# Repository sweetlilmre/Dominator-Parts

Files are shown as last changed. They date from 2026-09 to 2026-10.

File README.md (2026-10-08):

# Kreepy Krauly Dominator replacement parts

This project gives 3D printed replacement parts for the Kreepy Krauly Dominator pool cleaner:

- **The cam assembly:** the cam, the gear and the washer. The cam controls the steering of the cleaner.
- **Gearbox parts:** the reduction gear, the two drive shafts and drive gears 1, 2 and 3.

The design is parametric OpenSCAD. All dimensions are in `scad/config.scad`. You can change them in the OpenSCAD Customizer.

Words in this README have the meanings in `CONTEXT.md`.

| Cam assembly | Cam | Gear |
|---|---|---|
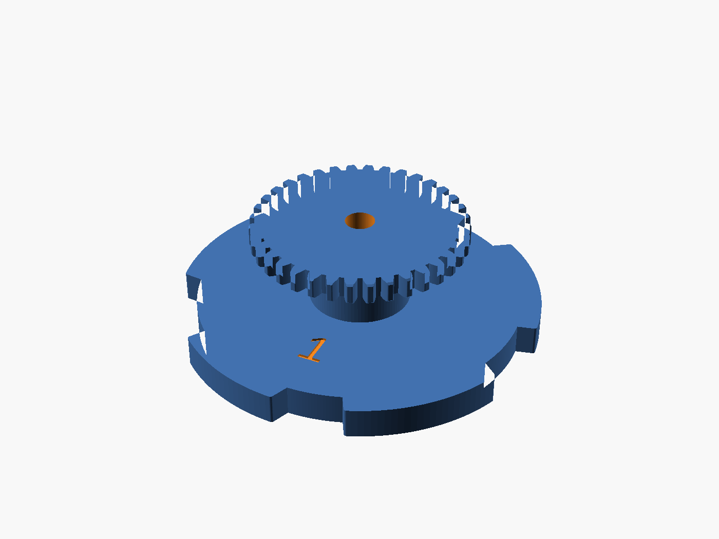
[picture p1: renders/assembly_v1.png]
Cam assembly
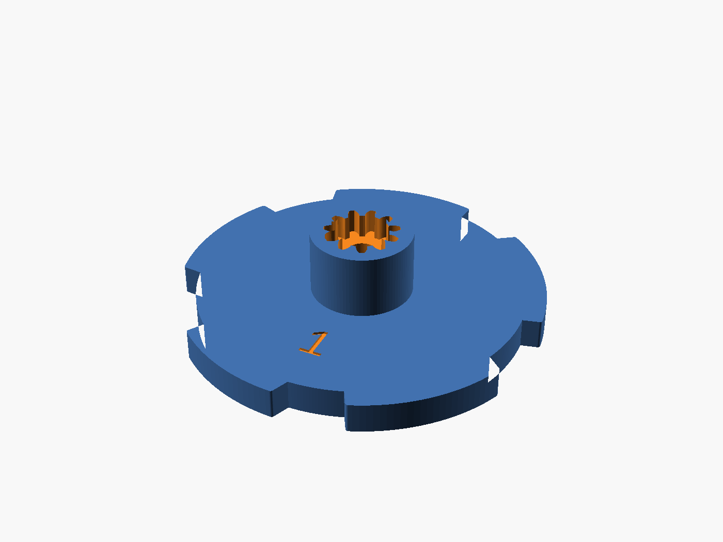
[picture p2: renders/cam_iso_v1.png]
Cam
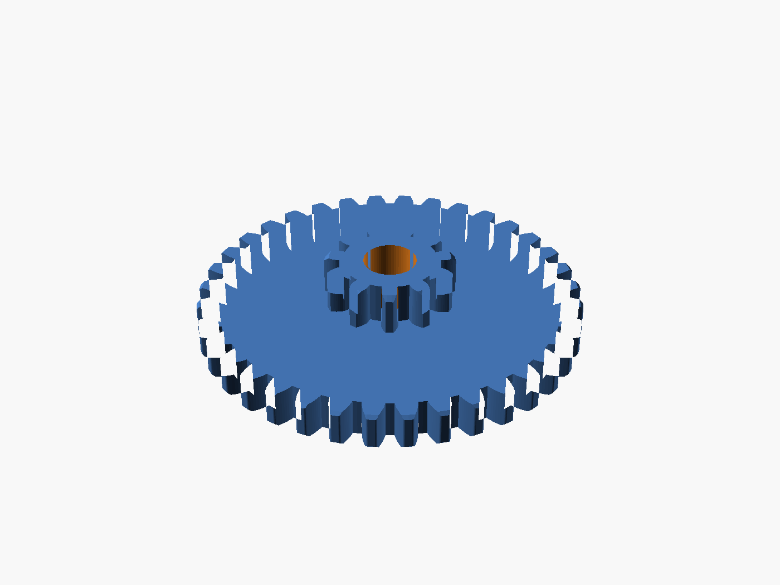
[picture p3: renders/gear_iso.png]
Gear
|  |  |  |

## Contents

1. [How the cam assembly works](#how-the-cam-assembly-works)
2. [The parts](#the-parts)
3. [Before you print: find the fit for your printer](#before-you-print-find-the-fit-for-your-printer)
4. [Modifiers: solid material where the parts wear](#modifiers-solid-material-where-the-parts-wear)
5. [Print the cam assembly](#print-the-cam-assembly)
6. [The two cam versions](#the-two-cam-versions)
7. [Gearbox parts](#gearbox-parts)
8. [Change the design](#change-the-design)
9. [Where the numbers come from](#where-the-numbers-come-from)
10. [Open items](#open-items)

## How the cam assembly works

The cam assembly turns on a steel pin in the gearbox. The gearbox drives the gear. The gear turns the cam.

The cam has five lobes on the rim of its plate. A follower in the gearbox rides on the rim. When a lobe comes to the follower, the follower goes up the ramp face and onto the crest. At the end of the lobe, the follower falls off the drop face into the next trough. Each lift of the follower changes the direction of the cleaner.

The cam and the gear are two separate printed parts:

- The **plug** on the hub side of the gear has spline teeth.
- The **socket** in the top of the hub has the same spline teeth.
- You push the plug into the socket. The gear then seats on the **shoulder** of the hub.
- The spline teeth transmit the torque. The shoulder holds the gear at the correct height.

Because the gear is a separate part, you can print a new gear without a new cam. You can also print it in a different material.

The **washer** goes on the pin between the gearbox wall and the cam side of the plate. It sets the position of the cam on the pin.

## The parts

| Part | What it does | STL file |
|---|---|---|
| Cam | The plate with the lobes, the hub and the socket. The follower runs on it. | `stl/dominator_cam_v1.stl` or `stl/dominator_cam_v2.stl` |
| Gear | The 36 tooth gear with the plug. It drives the cam. | `stl/dominator_gear.stl` |
| Washer | Sets the position of the cam on the pin. | `stl/dominator_washer.stl` |
| Fit test | A test part to find the spline fit for your printer. | `stl/dominator_fit_test.stl` |

Each part also has one or more modifier files. The section [Modifiers](#modifiers-solid-material-where-the-parts-wear) tells you which modifier goes with which part.

## Before you print: find the fit for your printer

The plug must be tight in the socket. If it is loose, the joint has play and the teeth wear. If it is too tight, the hub can split. Each printer makes holes and teeth a little differently, so the correct fit is different on each printer.

One value controls the fit: `spline_clearance` in `scad/config.scad`. It is the gap between the plug and the socket, in mm, on all sides of each tooth.

**Only the socket changes with `spline_clearance`.** The plug is always the nominal spline size. Thus you print the gear one time, and then you use it to test sockets.

| Printer | Material | Best `spline_clearance` |
|---|---|---|
| Owner's Prusa MK4 | PETG | 0.05 (the default) |
| A contributor's printer | not recorded | 0.15 |

These results show that the value is different on different printers. Do the test on your printer before you print a cam.

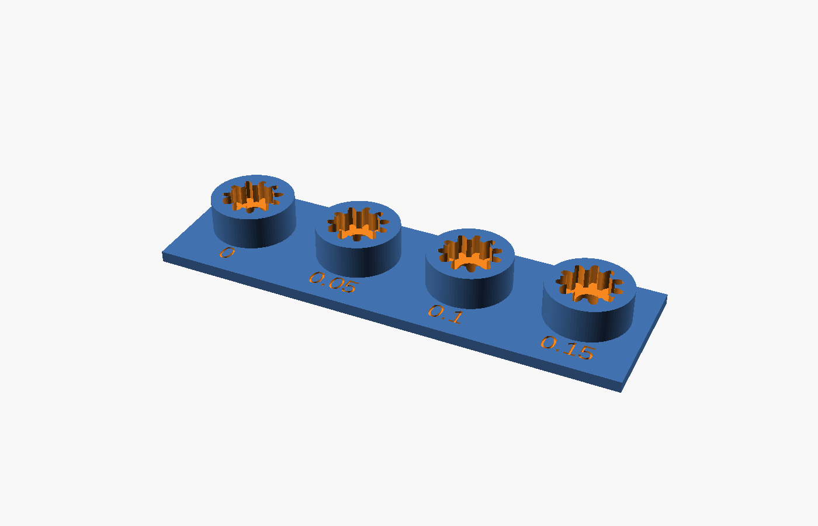
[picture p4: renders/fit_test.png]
Fit test


### Procedure

1. Print the gear (`stl/dominator_gear.stl`). Use its modifiers and the settings that you will use for the final parts.
2. Print the fit test (`stl/dominator_fit_test.stl`). Use the same material and settings. The fit test has four sockets, at clearances of 0, 0.05, 0.10 and 0.15. The clearance of each socket is engraved next to it.
3. Push the plug of the gear into each socket, one at a time.
4. Find the socket that holds the plug tightly without play. The socket must not crack.
5. Write the clearance of that socket in `spline_clearance` in `scad/config.scad`.
6. Export the cam again (see [Change the design](#change-the-design)).
7. Record the result in `PRINT_LOG.md`.

If no socket gives a good fit, change the list `ft_clearances` in `scad/fit_test.scad`. Then print the fit test again.

### Why the test uses a real gear

The fit test cuts its sockets with the same OpenSCAD module as the cam. The sockets are in the same orientation as the socket in the cam. Thus a socket in the fit test is equal to the socket in the cam.

The gear gives you a real plug. It has the print errors of the real part. A test plug with a different shape or orientation would have different errors.

### The clearance is on the cam

The cam has its `spline_clearance` engraved on both faces of the plate, opposite the version number. You can read the value in the slicer before you print. You can also read it on the printed part. This prevents a print from an old STL file.

## Modifiers: solid material where the parts wear

### Why the parts need modifiers

Some surfaces of the cam assembly rub against other parts:

- On the **cam**, the follower rubs on the crests, ramp faces, drop faces and troughs. The plug pushes against the walls of the socket.
- On the **gear**, the teeth mesh with the gearbox. The plug transmits the torque into the socket.

A normal print has a thin skin of perimeters on sparse infill. At a surface that rubs, the skin wears through quickly. A fully solid part does not have this problem, but it uses much time and material.

A modifier is a second mesh that you load onto a part in the slicer. The slicer applies the settings of the modifier only inside the modifier mesh. Each modifier in this project covers one area that rubs. Inside the modifier, the infill is 100 percent. The rest of the part uses your normal infill.

### Which modifier goes with which part

| Part | Modifier file | Area it makes solid |
|---|---|---|
| Cam | `stl/dominator_cam_rim_modifier.stl` | The outer band of the plate: from 4 mm inside the trough circle to outside the crests. This includes all the lobes and troughs. |
| Cam | `stl/dominator_cam_socket_modifier.stl` | The full width of the hub, from 1.5 mm below the floor of the socket to the shoulder. This includes the walls and floor of the socket. |
| Gear | `stl/dominator_gear_tooth_modifier.stl` | The teeth, and 4 mm inside the root circle. |
| Gear | `stl/dominator_gear_core_modifier.stl` | The plug, and the gear body directly below it. |
| Reduction gear | `stl/dominator_gear_tooth_modifier.stl` | The teeth of the ring, and 4 mm inside the root circle. |
| Reduction gear | `stl/dominator_gear_core_modifier.stl` | The pinion, the plate, and the ring directly below them. |

Both cam modifiers fit v1 and v2. The rim modifier has the size of the taller v2 lobes. On the v1 cam it goes past the crests, which has no effect.

Do not put a gear modifier on the cam. The plug on the gear and the socket on the cam are at different heights. Thus a gear modifier does not cover the socket.

### Put each setting in the correct place

- Set **Fill density = 100 percent on the modifier**. Do not add other settings to the modifier.
- Set **Perimeters on the part**, not on the modifier.

If you set perimeters on a modifier, the slicer makes perimeters around all edges of the modifier. This includes the inner edge of the ring in the middle of the plate. These perimeters have no function. When the modifier changes only the infill, the slicer does not make these perimeters.

### Procedure in PrusaSlicer

1. Import the STL of the part.
2. Right-click the part in the object list. Select Add settings, Layers and perimeters. Set Perimeters.
3. Right-click the part. Select Add modifier, Load. Select the modifier STL. The modifier has the same origin as the part, so it goes into the correct position. Do not move or scale it.
4. Right-click the modifier. Select Add settings, Infill. Set Fill density to 100 percent.
5. Do steps 3 and 4 again for the second modifier of the part.
6. Slice the part. In the preview, make sure that the areas in the table above show solid infill. Make sure that there is no ring of perimeters at the inner edge of a modifier.

`SLICING.md` gives more information about these settings.

## Print the cam assembly

Find the fit for your printer first. See [Before you print](#before-you-print-find-the-fit-for-your-printer).

| Part | Orientation | Perimeters | Modifiers | Supports |
|---|---|---|---|---|
| Cam | Cam side on the bed, hub up | 3 | rim and socket | none |
| Gear | Flat side on the bed, plug up | 3 | tooth and core | none |
| Reduction gear | Ring on the bed, pinion up | 3 | tooth and core | none |
| Washer | Flat | 3 | none, use 100 percent infill | none |

All STL files are in the correct orientation for printing. Do not turn them.

Settings for all parts:

- Layer height: 0.12 to 0.2 mm. Thinner layers give smoother tooth flanks.
- Nozzle: 0.4 mm.
- Material: PETG, ASA or nylon. Do not use PLA. PLA becomes soft in a hot pool.
- Speed: use a low speed for the external perimeters of the cam. The lobe faces are the surfaces that the follower runs on.

### Assemble

1. Push the plug of the gear into the socket of the cam. Push until the gear seats on the shoulder.
2. Put the washer on the pin.
3. Put the cam assembly on the pin, cam side to the washer.

## The two cam versions

The OEM cam has a number on both faces. Two numbers are known, v1 and v2. The owner has one of each. The two versions are the same in all measured dimensions, but for these:

| | v1 | v2 |
|---|---|---|
| Lobe height | 4 mm | 5 mm |
| Span across the crests | 79 mm | 81 mm |
| Lobe widths, in sequence | 49.9, 41.1, 46.0, 49.9, 49.5 deg | 50, 43, 41, 49.5, 49.5 deg |
| Largest trough | 32.5 deg | 35.5 deg |

Find the number on your old cam. Print the cam with the same number.

- In the Customizer, set `cam_version`.
- With `render.ps1`, use `-CamVersion v1` or `-CamVersion v2`.

The printed cam has its version number engraved on both faces, as the OEM cam does. Only the cam changes with the version. All other parts and all modifiers fit both versions.

| v1 | v2 |
|---|---|
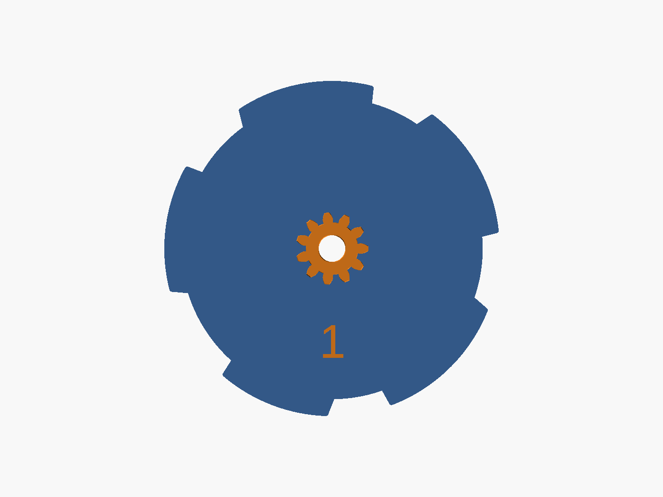
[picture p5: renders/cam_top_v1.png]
Cam v1
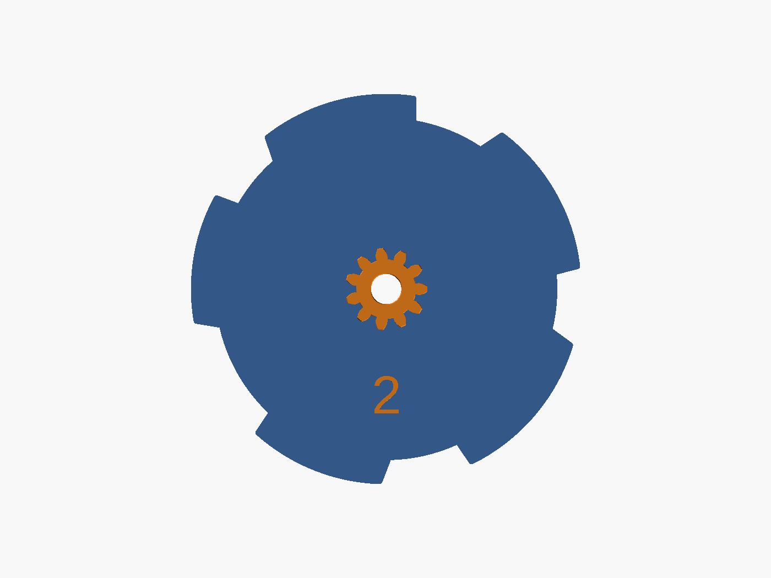
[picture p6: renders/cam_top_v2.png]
Cam v2
|  |  |

## Gearbox parts

These parts are not part of the cam assembly. They replace other worn parts in the gearbox. Use the same material as for the cam assembly.

### Reduction gear

`stl/dominator_reduction_gear.stl` is one of the gears between the turbine and the cam. It has a 36 tooth ring and an 11 tooth pinion on top. The pinion drives the gear of the cam assembly. Its dimensions are in the `[Reduction gear]` section of the config. They do not change when you change the gear of the cam assembly.

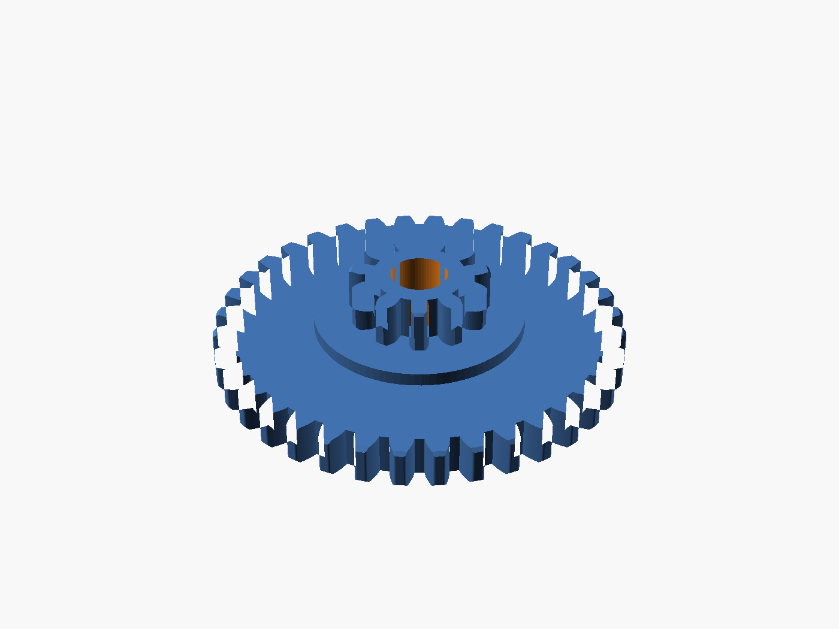
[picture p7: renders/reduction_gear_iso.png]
Reduction gear


### Drive shafts

`stl/dominator_shaft_long.stl` and `stl/dominator_shaft_short.stl` are the two drive shafts. Each drive shaft is an 8 tooth pinion along its full length, with round body sections.

| | Long | Short |
|---|---|---|
| Length | 177 mm | 83 mm |
| Gear tip diameter | 12.45 mm | 12.45 mm |
| Gear lengths, A end / B end | 12 / 50 mm | 18 / 25 mm |
| Body diameter | 12.5 mm, 10 mm between the gear seats | 12.5 mm |

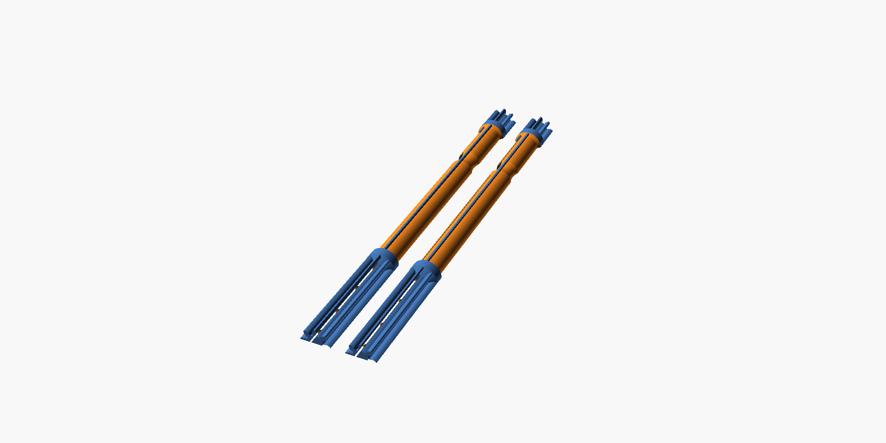
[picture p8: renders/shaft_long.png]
Long drive shaft


Each STL has two equal halves. The halves lie flat on the bed. You glue them together after printing.

- **Why halves:** A drive shaft printed vertically broke at the step between the gear and the body. The layer lines went across the drive shaft at that point. Flat halves put the layer lines along the drive shaft.
- **Split through the tooth centres:** Each half has whole teeth up. It has a half tooth flat on the bed at each side. Thus no tooth has an overhang.
- **Dowel holes:** A line of holes on the axis holds short pieces of 1.75 mm filament. The dowels align the two halves, also in the gear sections.
- **Root fillets:** A 2 mm cone at each body end goes into the tooth roots. This removes the sharp step where the vertical print broke.

To print and assemble a drive shaft:

1. Print the halves with 3 perimeters and 100 percent infill. The parts are small, so they do not need modifiers.
2. Put the dowels into the holes of one half.
3. Put the two halves together without glue. Make sure that they align.
4. Glue the halves. Clamp them along the full length. PVC pipe cement gave a strong joint (see `PRINT_LOG.md`).

All settings are in the `[Drive shafts]` section of the config.

### Drive gear 1

`stl/dominator_drive_gear_1.stl` is a compound gear from the gearbox. It has a
26 tooth gear with a 19 tooth gear on the same axis. It turns on the pin. The 19
tooth gear meshes with the pinion of a drive shaft.

| | 26 tooth gear | 19 tooth gear |
|---|---|---|
| Tip diameter | 35 mm | 26.25 mm |
| Face width | 10 mm | 11 mm |
| Module | 1.25 | 1.25 |

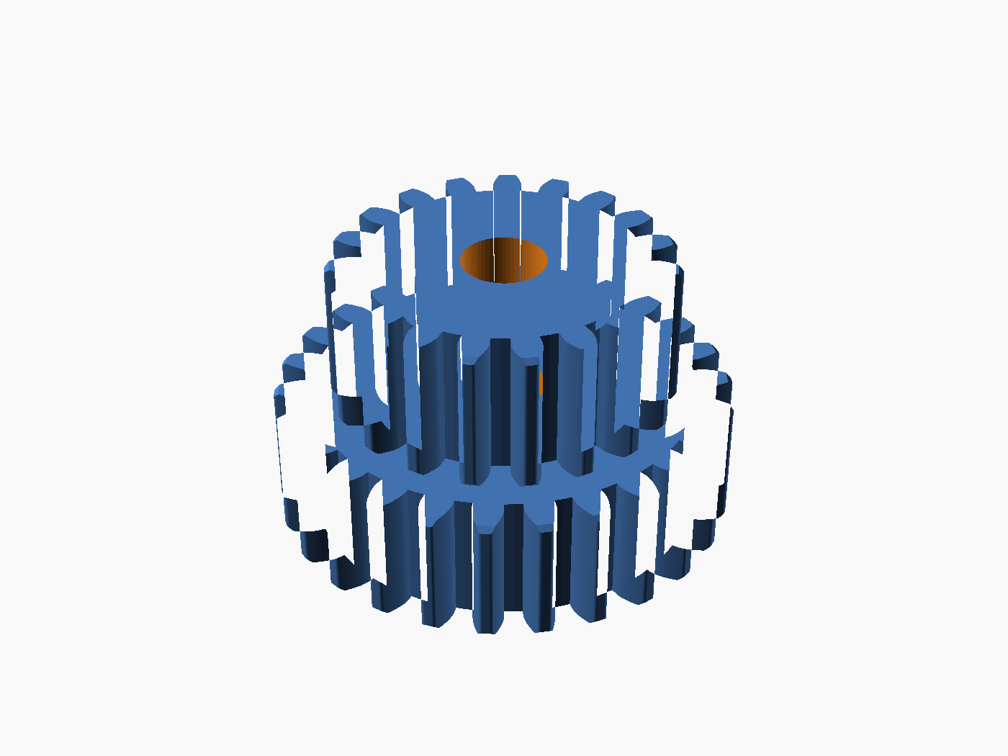
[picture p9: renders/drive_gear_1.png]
Drive gear 1


Both gears use one module. The module comes from the 26 tooth gear, because 26
is an even number: a caliper touches two opposite tooth tips, so the reading is
correct. 19 is an odd number, so a caliper cannot touch two opposite tips and
the reading is too small. The owner read 25 to 26 mm for a true 26.25 mm. The
model therefore calculates the 19 tooth diameter from the module. If you get a
better measurement, put the value in `dg1_inner_od`.

The teeth are a standard depth. They are not short like the teeth of the gear of
the cam assembly. The drive shaft pinion that this gear meshes with also uses
the standard depth.

The OEM part has slots in one face to save material. The printed part is solid.
The slots save moulding material and prevent shrinkage. A printed part does not
need this, and a solid part is stronger.

To print drive gear 1: put the 26 tooth gear on the bed. You do not need
supports. The bore goes through both gears.

All settings are in the `[Drive gear 1]` section of the config.

### Drive gear 2

`stl/dominator_drive_gear_2.stl` is a 23 tooth gear from the gearbox. It meshes
with the 19 tooth gear of drive gear 1. It has a spacer on each face. The
spacers hold the gear away from its neighbours on the pin, so they are a part of
the gear and not separate washers.

| Item | Value |
|---|---|
| Teeth | 23 |
| Tip diameter | 31.25 mm |
| Module | 1.25 |
| Gear body width | 15 mm |
| Spacer | 1.5 mm high, 14 mm diameter, one on each face |
| Total height | 18 mm |

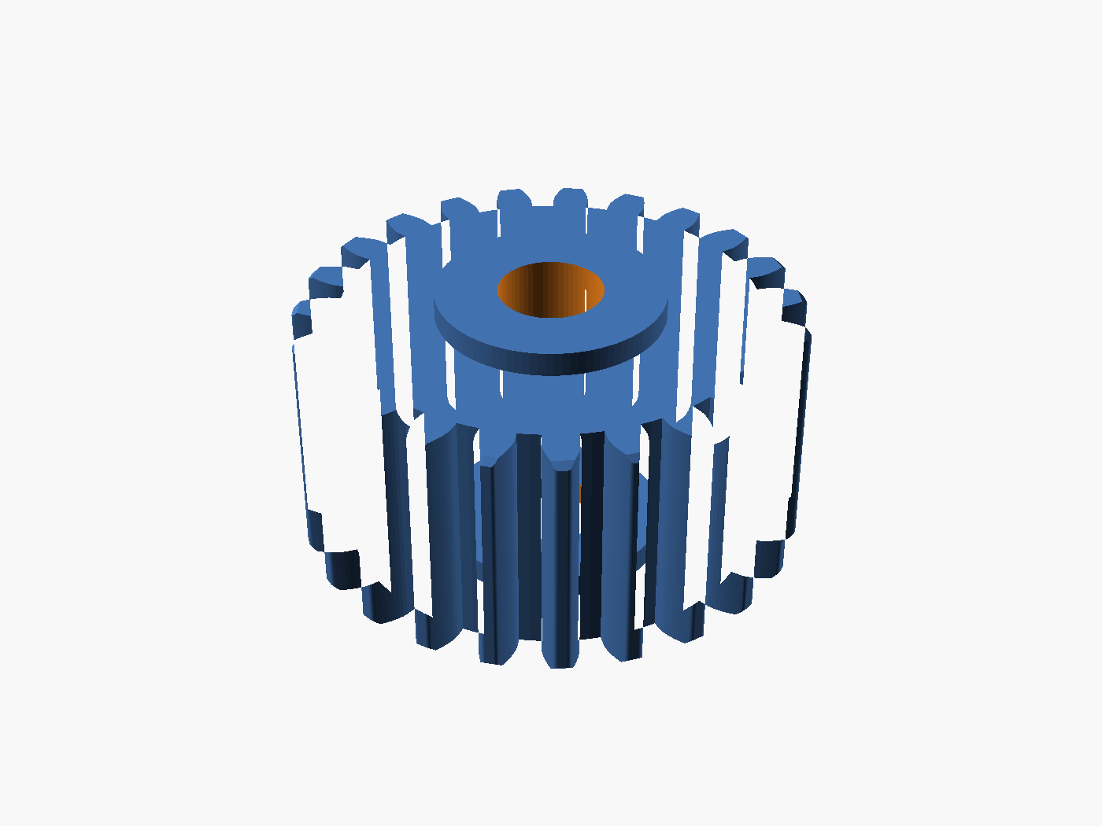
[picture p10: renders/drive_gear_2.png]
Drive gear 2


The module is not a value of its own. It comes from drive gear 1, because the
two gears mesh and meshing gears must have the same module.

The tip diameter is calculated from the module, not measured. 23 is an odd
number, so no tooth is opposite another tooth. A caliper cannot touch two
opposite tips, and the reading is too small: the owner read 30 mm for a true
31.25 mm.

The gear body is 15 mm. A trace of the side photograph gave 17 to 19 mm, but a
print showed that the caliper reading of 15 mm is correct (see `PRINT_LOG.md`).

To print drive gear 2: put one spacer on the bed. You do not need supports. The
spacer is small, so use a brim if the part comes loose.

All settings are in the `[Drive gear 2]` section of the config.

### Drive gear 3

`stl/dominator_drive_gear_3.stl` is a 26 tooth gear that connects the two drive shafts. Drive gear 2 turns it. It has a boss on each face. Each boss has an 8 lobe socket for a drive shaft:

- The long shaft goes into the long boss.
- The short shaft goes into the short boss.

The gear does not turn on the pin. It has no bore. A solid wall separates the two sockets.

| Item | Value |
|---|---|
| Teeth | 26 |
| Tip diameter | 35 mm |
| Module | 1.25 |
| Gear face width | 11 mm |
| Boss diameter | 18 mm |
| Short boss / long boss | 5 mm / 14 mm |
| Total height | 30 mm |
| Short socket / long socket depth | 17 mm / 12 mm |
| Wall | 1 mm, at the face of the gear on the long boss side |

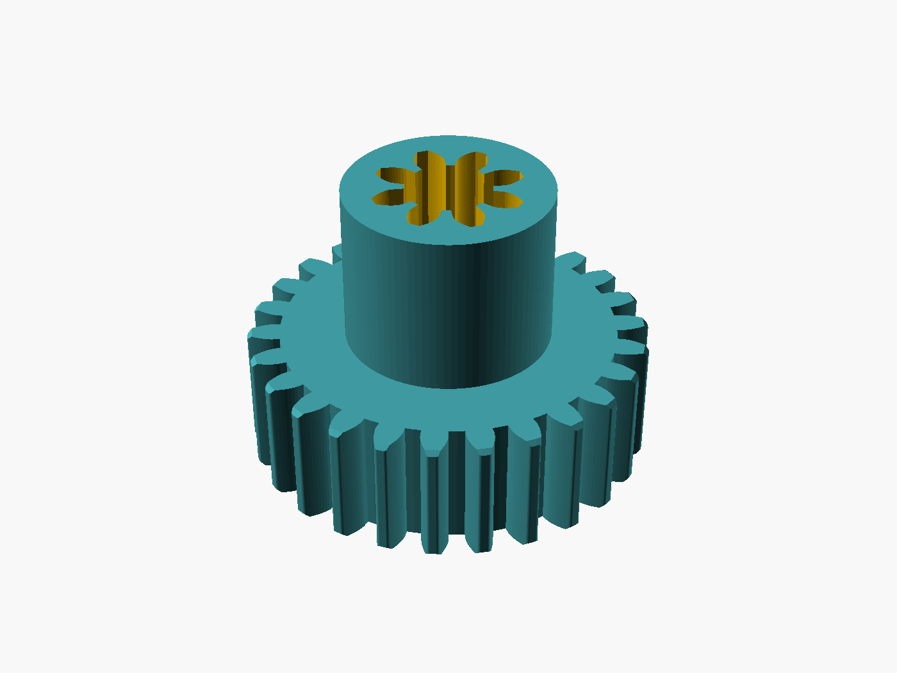
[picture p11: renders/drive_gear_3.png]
Drive gear 3


The module comes from drive gear 1, because drive gear 3 meshes with drive gear 2. The 35 mm tip diameter agrees: 26 is an even number, so the caliper reading is correct.

The sockets have the tooth profile of the drive shaft pinion. `dg3_socket_clearance` adds a gap of 0.3 mm on all sides. This gives a slide fit, because the shafts are loose in the OEM part. If a shaft is too tight or too loose, change the value and print the gear again.

To print drive gear 3:

1. Print it in one piece, as exported, with the short boss on the bed. You must use supports under the gear, because the gear is wider than the boss below it. Put supports only there: use paint-on supports or "Support on build plate only". Make sure that no supports go into the short socket, and tick "Don't support bridges". The wall between the sockets prints as a 13 mm bridge over the short socket.
2. If the part is not stable on the bed, use a brim.
3. Push each drive shaft into its socket. Make sure that it slides in and turns the gear without play.

All settings are in the `[Drive gear 3]` section of the config. Set `dg3_split = true` to print the gear in two halves instead. The halves are cut across the axis at the middle of the gear. They print on their cut faces, and you glue them together with four 1.75 mm filament dowels.

## Change the design

### Files

| Path | Contents |
|---|---|
| `scad/assembly.scad` | Open this file in OpenSCAD. Select `part` in the Customizer. |
| `scad/config.scad` | All parameters. Each value shows where it comes from. |
| `scad/cam.scad` | The cam, the washer and the cam modifiers. |
| `scad/cam_gear.scad` | The gear and the gear modifiers. |
| `scad/fit_test.scad` | The fit test. |
| `scad/reduction_gear.scad` | The reduction gear. |
| `scad/drive_shaft.scad` | The two drive shafts. |
| `scad/drive_gear.scad` | The drive gears. |
| `scad/lib/involute_gear.scad` | An involute spur gear library. It has no external dependencies. |
| `render.ps1` | Exports the parts to `stl/`. |
| `render_previews.ps1` | Makes the PNG images in `renders/`. |
| `PRINT_LOG.md` | One entry for each print: the config, the result, and the changes. |
| `SLICING.md` | More information about the slicer settings. |
| `CONTEXT.md` | The words for the parts and their features. |
| `measure/` | Photos with labels, and tables of the measurements to take, for each cam version. |
| `reference/` | The owner's photos of each cam version. |

### Export the STL files

You need the OpenSCAD command line. Install OpenSCAD from the official OpenSCAD website.

```powershell
.\render.ps1                          # all parts, cam version v1
.\render.ps1 cam gear                 # only the parts that you name
.\render.ps1 -CamVersion v2           # all parts, cam version v2
.\render_previews.ps1                 # the PNG images in renders\
```

The script works in Windows PowerShell 5.1 and in PowerShell 7. It uses `openscad.com`, the console version of OpenSCAD. Do not use `openscad.exe` for scripts: it is the GUI version, and it does not write files from the command line.

### Parameters that you can change

| Parameter | Default | What it does |
|---|---|---|
| `spline_clearance` | 0.05 | The gap between the plug and the socket. Find it with the fit test. |
| `bore_clearance` | 0.4 | The added diameter of the bore, so the cam turns freely on the pin. Use 0.3 to 0.5. |
| `gear_backlash` | -0.2 | A negative value makes the gear teeth thicker. The OEM teeth are thicker than a standard involute. If the gears bind, increase the value toward 0. |
| `plug_h` | 5 | How far the plug goes into the socket. The socket is `socket_extra` deeper, so the gear seats on the shoulder. |
| `ramp_lean`, `drop_lean` | 21, 9 | The lean of the ramp face and the drop face. 0 gives radial faces. |
| `cam_clearance_mark_size` | 5 | The text size of the engraved clearance. 0 removes it. |
| `socket_band` | 1.5 | How far the socket modifier goes below the floor of the socket. |

## Where the numbers come from

| Item | Value | Source |
|---|---|---|
| Trough circle | 71 mm | owner's calipers |
| Plate thickness | 6.6 mm | owner's calipers |
| Lobe height | v1 4 mm, v2 5 mm | owner's calipers; photo trace gives 4.15 and 4.5 |
| Lobe angles, v1 | 20.2-70.1, 90.4-131.5, 164-210, 235-284.9, 305.5-355 deg | traced from `reference/cam_v1/own_cam_top_v1.jpg` |
| Lobe angles, v2 | 15-65, 90-133, 168.5-209.5, 230-279.5, 305-354.5 deg | traced from `reference/cam_v2/own_cam_top_v2.jpg` |
| Lean | ramp face 21 deg, drop face 9 deg | line fit on each face in the same photo |
| Outline mirrored | `cam_mirror = true` | The trace photo shows the cam side. The gear side photo `reference/cam_v2/own_gear_side_v2.jpg` confirms the mirror. |
| Gear | 36 teeth, 47 mm tip diameter, 4.6 mm thick | owner's count and calipers |
| Gear tooth thickness | `gear_backlash = -0.2` | The OEM teeth are about 0.1 of the pitch thicker than a standard involute. Measured on `reference/cam_v2/own_gear_side_v2.jpg`. |
| Gear tooth depth | `gear_dedendum = 1.0` | The OEM teeth are about 2.4 mm deep, less than a standard tooth. Same photo. |
| Hub | 22 mm diameter, 14 mm from the plate to the shoulder | owner |
| Pin | 6.00 mm | owner. The worn OEM bore measured 6.3. |
| Washer | 2 mm | estimate |
| Reduction gear pinion | 11 teeth, 16 mm tip diameter | owner |

The outlines come from the owner's photos. The photos were taken straight down. They were scaled with the grid of the cutting mat and the trough circle measured on the ruler photos. The v1 method, applied to the v2 photo, gives the v2 lobe widths within 1.5 degrees. This is the accuracy of the lobe angles.

### The spline is not an OEM dimension

The plug, the socket and all `spline_*` parameters are a design of this project. They let you print the gear as a separate part. The photos do not show how the OEM parts join. Thus the division into a cam and a gear is a decision for printing. It is not a copy of the OEM part.

The spline has 11 teeth and a 16 mm tip diameter. This is the same size as the pinion of the reduction gear, so the project has one small tooth size. The spline and the pinion have separate parameters. The mesh with the gear controls the pinion. The hub wall and the fit control the spline. A change to one must not change the other.

The spline teeth are shorter than the pinion teeth (`spline_addendum` 0.9). This keeps more material around the bore.

## Open items

1. Measure `washer_t`: the distance from the gearbox wall to the cam side of the OEM plate.
2. Measure the stack height of the OEM cam assembly. Compare it with the stack height that OpenSCAD shows in the console.
3. Hold the printed cam with the gear side up and 0 degrees to your right. The ramp face of each lobe must be on the counter-clockwise side. If it is not, set `cam_mirror = false` and change the two lean values with each other.
4. Print the cam and the gear at `spline_clearance = 0.05`. The fit test found this value on the owner's printer, but the full parts are not yet printed at this value.

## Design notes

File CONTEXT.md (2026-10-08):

# Dominator Replacement Parts

Vocabulary for the 3D printed replacement parts of the Kreepy Krauly Dominator pool cleaner: the cam assembly and the gearbox parts. The cam turns in the gearbox and its lobes lift a follower that changes the cleaner's direction.

## Language

### Parts

**Cam assembly**:
The cam, gear and washer on the pin.
_Avoid_: cam kit, steering cam

**Cam**:
The flat lobed part that the follower runs on, with its hub. The part that wears.
_Avoid_: cam plate, cam disc, tray

**Cam version**:
Which moulding of the cam a part or measurement refers to, taken from the number stamped on both faces. v1 and v2 differ in the lobe pattern and the lobe height only. Selected by `cam_version`.
_Avoid_: revision, mark, type, generation

**Plate**:
The flat body of the cam from which the lobes and hub rise.
_Avoid_: floor, disc

**Hub**:
The upright cylinder on the cam that carries the gear and holds the socket.
_Avoid_: shaft, post, boss

**Gear**:
The 36 tooth spur gear that drives the cam, a separate part carrying the plug.
_Avoid_: ring gear, cam gear

**Washer**:
The flat ring on the pin between the gearbox wall and the cam.
_Avoid_: spacer, shim

**Pin**:
The steel rod through the gearbox on which the cam assembly turns.
_Avoid_: shaft, axle, spindle

**Follower**:
The part of the gearbox that rides on the cam's lobes and triggers the steering. Not part of the cam assembly.
_Avoid_: pawl, finger, follower gear

**Reduction gear**:
One of the gearbox gears between the turbine and the cam: a ring with a pinion on top. A gearbox part, not part of the cam assembly. Its ring reads the same as the gear today but is dimensioned separately.
_Avoid_: follower gear, compound gear, cam gear kit gear

**Gearbox parts**:
The printed replacements for gearbox parts outside the cam assembly: the reduction gear, the drive shafts and the drive gears.
_Avoid_: optional parts, extras

**Pinion**:
The small toothed wheel on top of a reduction gear that drives the next gear in the train.
_Avoid_: small gear, spur

**Drive shaft**:
One of the two long gearbox shafts, long and short, that carry an 8 tooth pinion profile along their length and transfer drive to the wheels. A gearbox part, not part of the cam assembly.
_Avoid_: axle

**Drive gear**:
One of the gears in the gearbox that drives the drive shafts. Numbered 1 to 3 after the owner's photographs. Drive gear 1 is a compound gear: a 26 tooth gear with a 19 tooth gear on the same axis. Drive gear 2 is a single 23 tooth gear and meshes with drive gear 1's 19 tooth gear. Drive gear 3 is a 26 tooth gear driven by drive gear 2; it does not turn on the pin but joins the long and short drive shafts, which fit into a socket in each of its two bosses. A gearbox part, not part of the cam assembly.
_Avoid_: drive shaft, idler, transfer gear

### Spline joint

**Spline**:
The involute tooth pattern shared by the plug and the socket, and by extension the joint they form. Carries torque from gear to cam.
_Avoid_: key, keyway

**Plug**:
The male toothed part on the underside of the gear.
_Avoid_: boss, post, spline post

**Socket**:
The female toothed hole in the top of the hub that receives the plug.
_Avoid_: pocket, bore

### Lobe geometry

**Lobe**:
One of the five protrusions on the rim of the plate that lifts the follower.
_Avoid_: ear, bump, tab, notch

**Trough**:
The stretch of rim between two lobes where the follower rests.
_Avoid_: gap, dwell, valley, notch

**Trough circle**:
The circle the rim follows in the troughs, from which the lobes rise. Its diameter is the rim diameter.
_Avoid_: base circle (reserved for gear geometry), root diameter

**Crest**:
The outer face of a lobe that the follower rides along while lifted.
_Avoid_: top, land, outer face

**Ramp face**:
The sloped side face of a lobe, about 21 degrees from radial, that the follower rides up onto the crest. It is on the counter-clockwise side of each lobe when viewed from the gear side, and is the first face to reach the follower.
_Avoid_: leading face, trailing face, steep face, start edge, end edge, sloped edge

**Drop face**:
The near-radial side face of a lobe, about 9 degrees from radial, that the follower falls off into the trough.
_Avoid_: leading face, trailing face, shallow face, straight edge

**Lobe height**:
How far the crest stands out beyond the trough circle.
_Avoid_: ear out, bump height, protrusion

**Lean**:
The angle between a ramp or drop face and the radial line through the face's mid-height point.
_Avoid_: rake, slope angle, draft

**Face position**:
The angle around the cam at which a face sits, always taken at mid-height of the face. Changing a lean pivots the face about this point.
_Avoid_: root angle, corner angle

**Rotation direction**:
Counter-clockwise when viewed from the gear side, observed in the gearbox, so each lobe presents its ramp face to the follower first.

### Orientation

**Gear side**:
The side of the cam assembly from which the gear is visible; the plate face the hub rises from.
_Avoid_: top, front

**Cam side**:
The opposite side, the flat face of the plate that sits against the washer and gearbox wall.
_Avoid_: bottom, back, wall side, underside

**Hub side**:
The face of the gear that carries the plug and seats on the shoulder.
_Avoid_: underside, back

**Flat side**:
The plain face of the gear, the one printed against the bed.
_Avoid_: top, outer face

**Shoulder**:
The flat top of the hub around the socket on which the gear's hub side seats.
_Avoid_: seat, land

**Stack height**:
The distance from the gearbox wall to the flat side of the gear: washer plus plate plus hub plus gear thickness.
_Avoid_: overall height, assembly height, stack

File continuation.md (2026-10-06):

# Continuation notes

State of the Dominator parts project as of 2026-09-22, written so a fresh session can resume with no other context. Read `CONTEXT.md` for vocabulary before touching anything; use its terms (lobe, trough, ramp face, drop face, hub, plug, socket, pin, follower, reduction gear, drive shaft, cam version).

## What this repo is

Parametric OpenSCAD replacements for wearing parts of a Kreepy Krauly Dominator pool cleaner gearbox. Owner: Peter. Remote: GitHub `sweetlilmre/Dominator-Parts`. Work is on branch `cam_alt_version`. Commit messages end with a `Co-authored-by` trailer.

Files: `scad/assembly.scad` is the entry point (Customizer `part` and `cam_version` selectors), `scad/config.scad` holds every parameter with a source tag, `scad/lib/involute_gear.scad` is a dependency-free involute gear library. `render.ps1` exports STLs, `render_previews.ps1` regenerates the PNGs in `renders/`. `PRINT_LOG.md` records each physical print. `SLICING.md` explains perimeters versus infill and the modifier meshes. `measure/cam_v1/` and `measure/cam_v2/` hold the annotated measurement sheets. `reference/cam_v1/` and `reference/cam_v2/` hold the owner's photographs, and are tracked.

OpenSCAD 2021.01 is at `C:\Program Files\OpenSCAD\openscad.com`. Use the `.com`, not the `.exe`: the `.exe` is the GUI build and detaches without rendering.

## The two cam versions

The cam is moulded with a number on both faces. The owner has one of each. They differ in exactly two parameters, both on the plate:

| | v1 | v2 |
|---|---|---|
| `lobe_height` | 4 | 5 |
| Lobe widths | 49.9, 41.1, 46.0, 49.9, 49.5 | 50, 43, 41, 49.5, 49.5 |
| Largest trough | 32.5 deg | 35.5 deg |
| Outer span | 79 mm | 81 mm |

Everything else reads the same: trough circle 71, plate 6.6, hub 22 x 14, gear 36 T at 47, bore for a 6.0 mm pin. Select with `cam_version`, or `-CamVersion` on the scripts. Only the cam STL carries a `_v1` / `_v2` suffix; the rim modifier is sized from the taller lobes so one file serves both.

The printed cam engraves its version digit 0.5 mm into both faces, as the OEM moulding carries it (`cam_version_number_*`), and the `spline_clearance` its socket was cut at on the opposite side (`cam_clearance_mark_size`).

## Current design state

- **Cam**: flat plate 6.6 thick, trough circle 71, five lobes at the traced angles above, ramp face lean 21, drop face lean 9, `cam_mirror = true`. Hub 22 dia, 14 high, with an 11 tooth socket 16 mm across.
- **Gear**: 36 teeth, 47 OD, 4.6 thick, backlash -0.2, dedendum 1.0, tip round 0.3, with a matching 11 T / 16 mm plug. Prints flat side down, plug up.
- **Spline joint**: 11 T, 16 mm tip to tip, `spline_clearance = 0.15`. Sized to match the reduction gear pinion so the project has one small tooth size, but kept as separate parameters so a change to one cannot silently alter the other.
- **Washer** 2 x 16. Pin 6.0, bore clearance 0.4, bore 6.4.
- **Reduction gear**: owns its ring dimensions (`rg_ring_*`, 36 T at 47, 4.6 thick) rather than borrowing the cam gear's. Pinion measured at 11 T / 16 mm.
- **Drive shafts**: unchanged since 2026-09-10.
- **Fit test coupon** (`part = "fit_test"`): a plate of sockets at several clearances, pressed onto a printed gear's plug to find the fit without reprinting the cam.

## Decisions worth not relitigating

- **The reduction gear ring is decoupled from the cam gear.** They are different parts. The earlier arrangement, where the ring read `gear_teeth` and `gear_thickness` directly, meant editing the cam gear reshaped the reduction gear silently.
- **The pinion module is checked, not shared.** The pinion must mesh with the cam gear, so `assembly.scad` echoes a warning if the two modules differ by more than 2 percent. The old 12 T / 14.4 mm estimate was 16.8 percent out and could never have meshed; that is what the check exists to catch.
- **The spline is not an OEM dimension.** Earlier revisions of the README claimed the printed pieces were joined the same way as the OEM kit. Nothing in the photographs supports that, and the mating faces are never visible in any of them. The plug, socket and every `spline_*` value are this project's own design. How the OEM assembly divides is unresolved.
- **Tolerance scheme.** `spline_clearance` is applied as `offset(delta = clearance)` on the socket profile, so it is the gap normal to every flank, root and tip, and it does not scale with tooth count or diameter. Changing the spline size does not require retuning the fit.

## Measurement method and its traps

Outlines are segmented from the owner's straight-down photographs, sampled as radius against angle about the centroid, and scaled by the cutting-mat grid anchored to the trough circle from the ruler photograph. Running the pipeline over the v2 photograph reproduces the v2 lobe widths already in the config to within 1.5 degrees, which is the accuracy to trust.

Two traps, both hit during this work:

- **Parallax.** A ruler resting on the part sits about 12 mm closer to the lens than the mat it lies on, magnifying it by roughly 4 percent at phone range. Scale from a feature in the same plane as the thing being measured.
- **EXIF rotation.** Some photographs carry an orientation flag; `reference/cam_v2/own_cam_top_v2.jpg` is flagged 180 degrees. Libraries that ignore it read the array unrotated, silently rotating every angle measured from it.

## Open questions

1. **`spline_clearance` disagreement.** The fit test coupon says 0.15 grips best. Print 1 used 0.15 at the older 12 T / 14 mm spline and reported play. The differences are the spline size, the slicer settings (print 1 was PETG, 0.2 mm, 2 perimeters, 15 percent infill; the coupon's are unrecorded) and the host geometry (a 47 mm gear and 71 mm cam then, small pucks now). Unresolved; check the real parts.
2. **`washer_t`** has never been measured on either version: gearbox wall to the underside of the cam.
3. **v1 is only partly measured.** `plate_t`, `hub_h`, `hub_d`, `gear_od`, `gear_thickness` and both edge leans are assumed the same as v2. The leans are the ones worth checking, since the lobe widths differ.
4. **Print 2 of the cam assembly** has still never been reported.

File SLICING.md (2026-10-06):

# Slicing the cam assembly in PrusaSlicer

How to slice the cam and gear so the surfaces that rub are solid, without paying for a solid part everywhere. Terms follow `CONTEXT.md`.

## What needs to be strong

- **Cam**: the lobes and troughs. The follower runs on the crests, ramp faces, drop faces and troughs, so the outer band of the plate takes all the wear. The middle of the plate and the hub carry little load.
- **Gear**: the teeth, and the plug. The teeth mesh with the drive; the plug carries the torque into the socket.

Print 1 used 2 perimeters and 15 percent grid infill. That leaves a 0.9 mm skin over sparse infill at every contact surface, which is why it will wear quickly.

## The two settings, and where to put them

**Fill density** does the structural job. At 100 percent the region is solid and there is no skin to wear through.

**Perimeters** is a refinement. Perimeter lines follow the outline, so the material directly behind a lobe face is continuous extrusion running along the face. Solid infill is laid in parallel lines at 45 degrees, so at the face it ends in short segments meeting the wall at an angle, and it can leave tiny voids in narrow corners. A few perimeters give a tougher, cleaner contact skin with no wall-to-infill seam, but once the infill is solid more than 3 or 4 adds little. On the gear more perimeters can be worse: the teeth are so narrow they become nothing but perimeter anyway.

Put them in different places:

- **Fill density = 100 percent on a modifier**, so only the contact band is solid. A modifier that changes only infill does not create extra perimeters, because regions with the same perimeter settings are merged when perimeters are generated.
- **Perimeters on the object**, not on a modifier. If the perimeter count is set on a modifier, the modifier becomes its own region and the slicer draws perimeters around its whole boundary, including the inner edge of the ring in the middle of the plate. On the object, the only boundaries are the real outline and the bore.

## Recommended settings

| Part | Object setting | Modifier | Modifier setting |
|---|---|---|---|
| cam | Perimeters 3 | `stl/dominator_cam_rim_modifier.stl` and `stl/dominator_cam_socket_modifier.stl` | Fill density 100 percent |
| gear | Perimeters 3 | `stl/dominator_gear_tooth_modifier.stl` and `stl/dominator_gear_core_modifier.stl` | Fill density 100 percent |
| reduction gear | Perimeters 3 | `stl/dominator_gear_tooth_modifier.stl` and `stl/dominator_gear_core_modifier.stl` | Fill density 100 percent |
| washer | Perimeters 3, 100 percent infill globally | none | |

If you prefer one number, leave both objects at 3 perimeters and let the modifiers do the work. Going to 6 perimeters on the cam is harmless but unnecessary once the rim band is solid.

Other settings worth using:

- Slow the external perimeter speed on the cam, since the lobe faces are the working surface.
- 0.12 to 0.2 mm layers, 0.4 mm nozzle. Finer layers give smoother tooth flanks.
- PETG, ASA or nylon. PLA goes soft in a hot pool box.
- No supports on any part in the exported orientations: cam plate down and hub up, gear flat side down and plug up.

## Steps in PrusaSlicer

1. Import the part STL.
2. Right click the part in the object list, Add settings, Layers and perimeters, set Perimeters.
3. Right click the part, Add modifier, Load, pick the modifier STL. It is exported on the same origin and in the same orientation as the part, so it lands in place. Do not move or scale it.
4. Right click the modifier, Add settings, Infill, set Fill density to 100 percent. Add nothing else to the modifier.
5. Repeat 3 and 4 for the second modifier on each part.
6. Slice and check the preview: the rim band, hub around the socket, teeth and plug should show solid infill, the rest of the plate your global infill, and there should be no ring of perimeters at the modifier's inner edge.

## What the modifiers cover

| Modifier | Covers | Config value |
|---|---|---|
| `dominator_cam_rim_modifier` | outer band of the plate from 4 mm inside the trough circle to beyond the crests, plus half a millimetre above and below the plate | `rim_band` |
| `dominator_cam_socket_modifier` | the whole hub width from 1.5 mm below the socket floor to above the hub top, so the socket walls and floor are solid; one file fits either version | `socket_band` |
| `dominator_gear_tooth_modifier` | the teeth and 4 mm inside the root circle, full ring thickness, on the gear and on the reduction gear. One file fits both | `gear_band` |
| `dominator_gear_core_modifier` | on the gear, the plug and the gear body directly under it; on the reduction gear, the pinion, the plate and the ring under them. One file fits both | |

They are OpenSCAD parts in `scad/assembly.scad`, regenerated by `render.ps1`, so they track any change to the geometry.

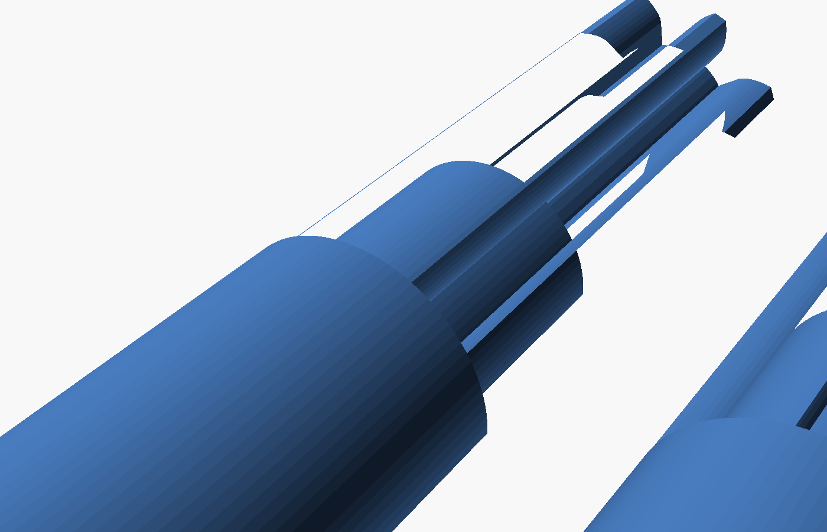
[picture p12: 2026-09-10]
renders/shaft_short_detail.png

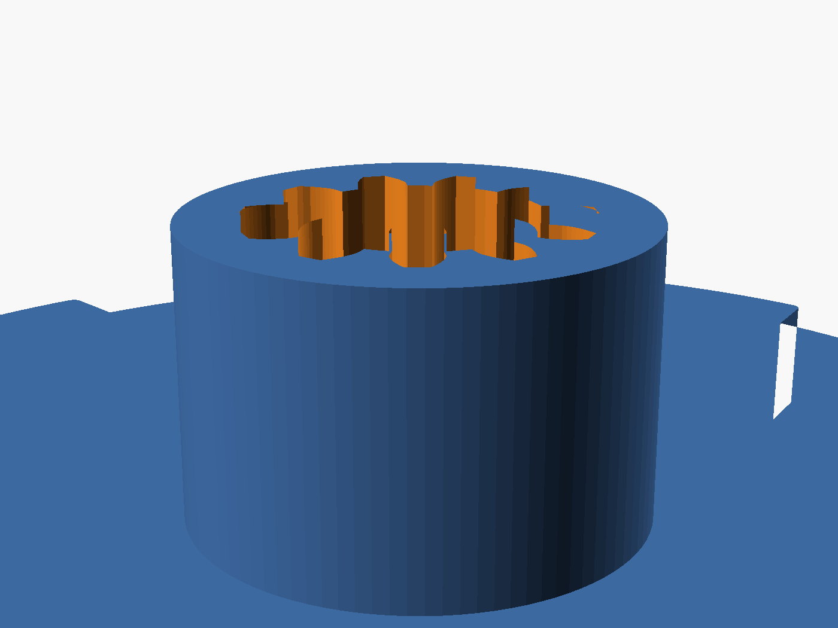
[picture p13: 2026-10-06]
renders/spline_closeup.png

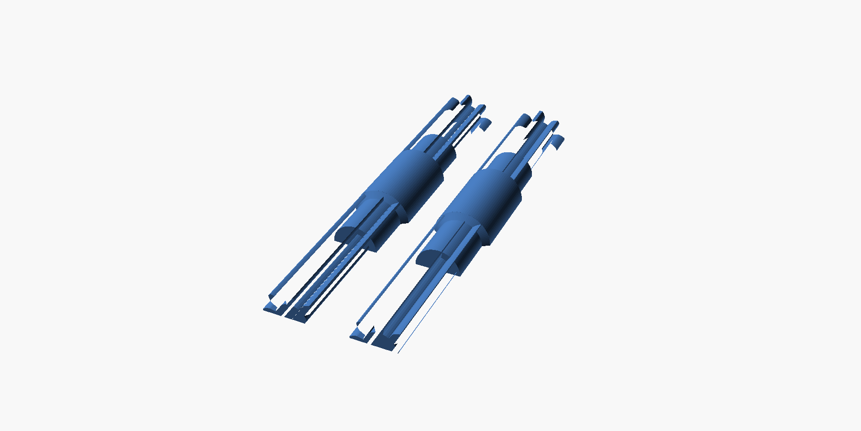
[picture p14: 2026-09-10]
renders/shaft_short.png

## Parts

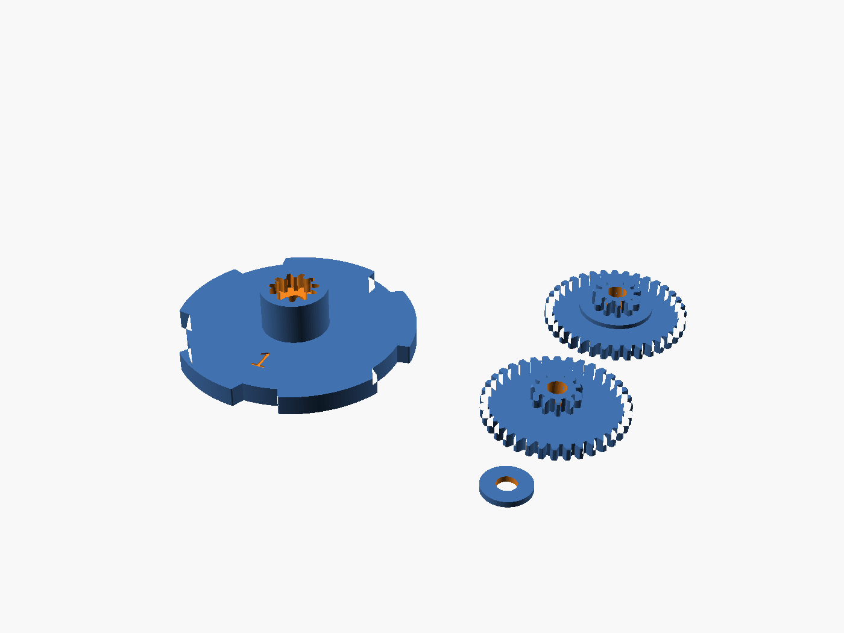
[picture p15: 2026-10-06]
renders/all_parts_v1.png

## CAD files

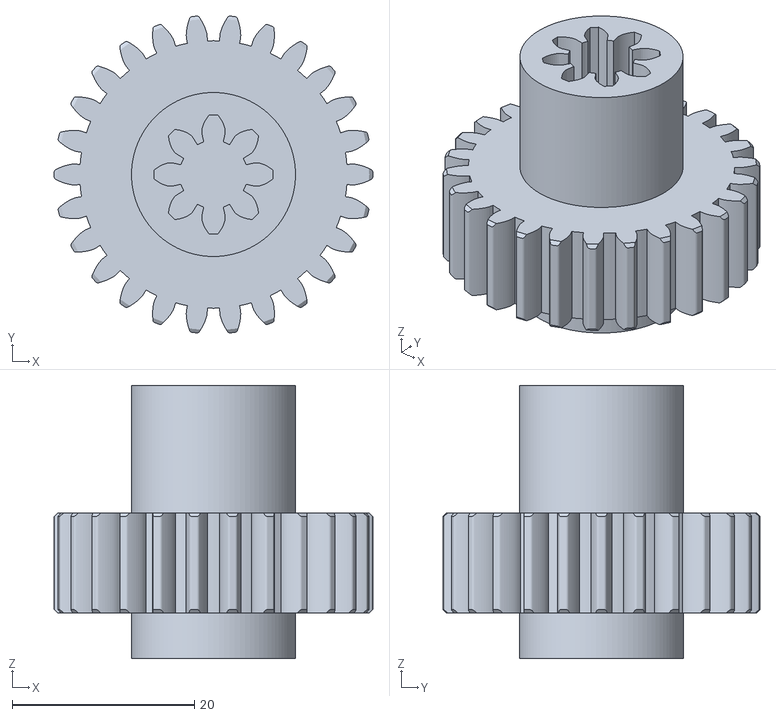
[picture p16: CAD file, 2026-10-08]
stl/dominator_drive_gear_3.stl
35.0 x 34.8 x 30.0

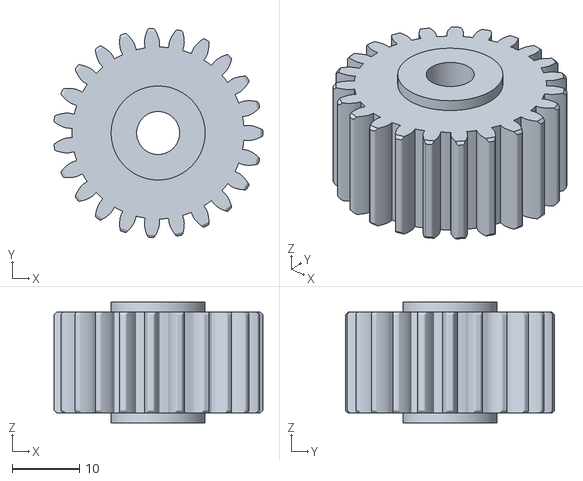
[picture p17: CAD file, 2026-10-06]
stl/dominator_drive_gear_2.stl
31.1 x 31.2 x 18.0

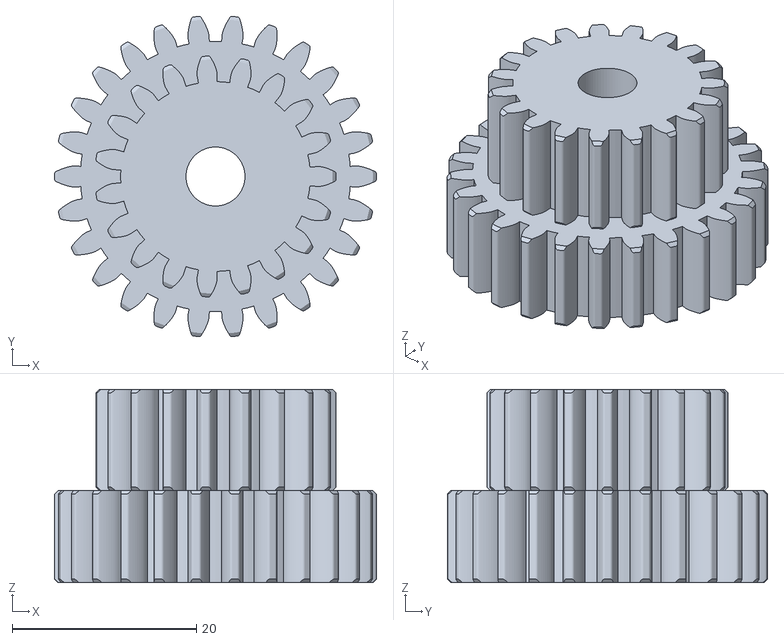
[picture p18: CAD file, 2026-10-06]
stl/dominator_drive_gear_1.stl
35.0 x 34.8 x 21.0

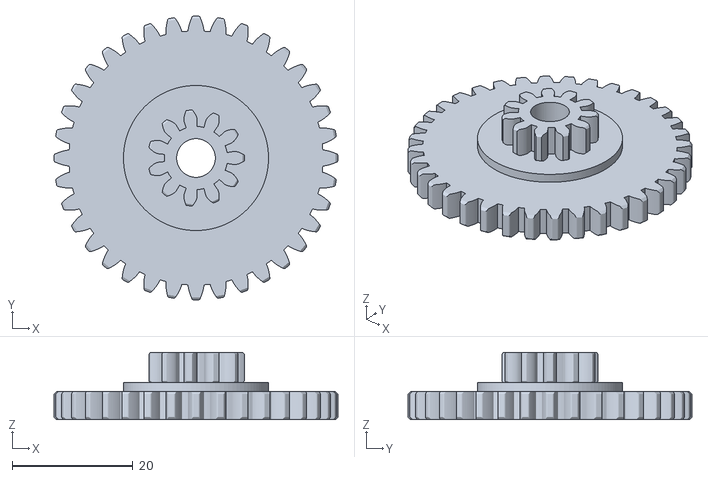
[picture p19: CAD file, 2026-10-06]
stl/dominator_reduction_gear.stl
47.0 x 47.0 x 11.1

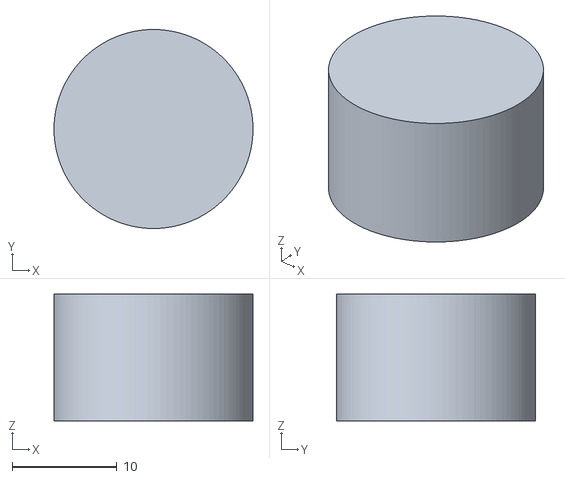
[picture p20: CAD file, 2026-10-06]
stl/dominator_gear_core_modifier.stl
19.0 x 19.0 x 12.1

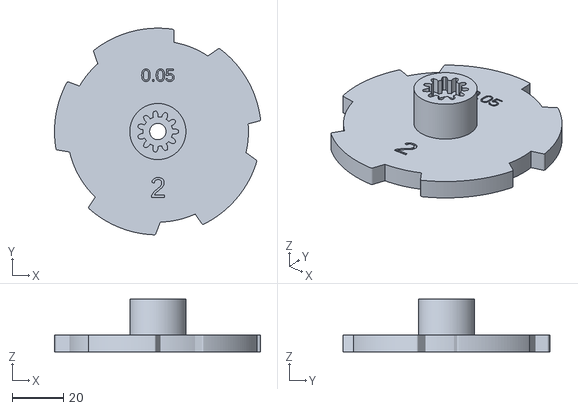
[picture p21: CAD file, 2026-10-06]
stl/dominator_cam_v2.stl
80.7 x 81.0 x 20.6

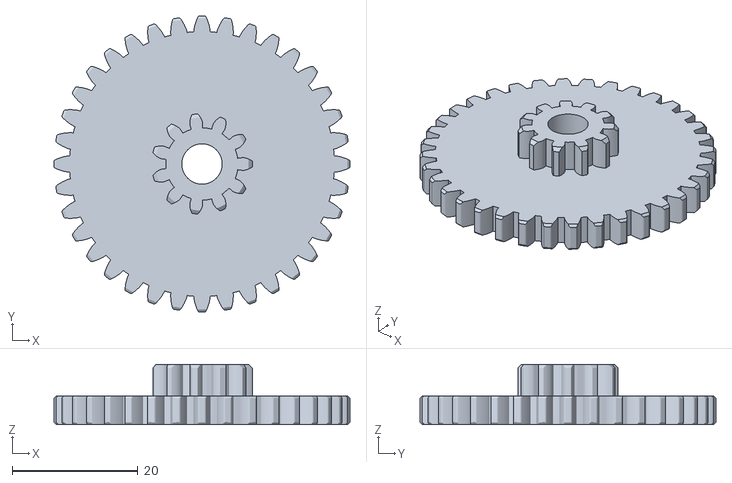
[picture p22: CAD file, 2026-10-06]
stl/dominator_gear.stl
47.0 x 47.0 x 9.60

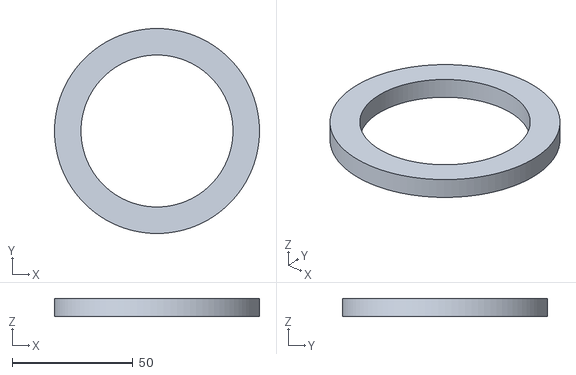
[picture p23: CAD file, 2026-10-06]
stl/dominator_cam_rim_modifier.stl
85.0 x 85.0 x 7.60

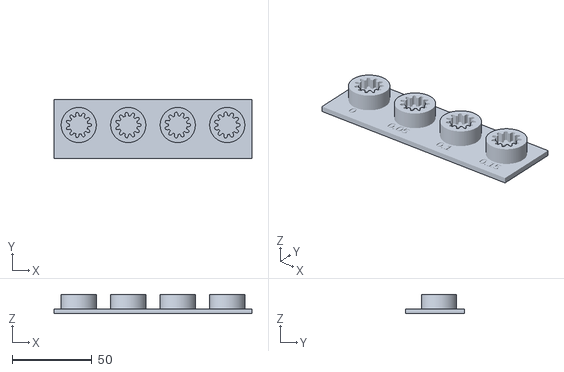
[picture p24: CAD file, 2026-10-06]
stl/dominator_fit_test.stl
124.0 x 37.2 x 12.0

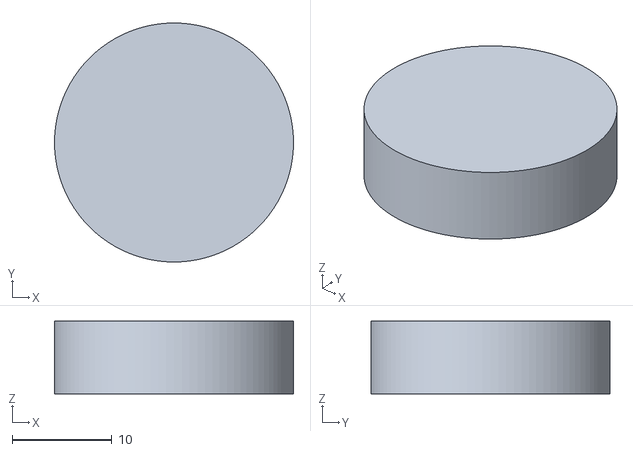
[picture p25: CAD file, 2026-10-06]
stl/dominator_cam_socket_modifier.stl
24.0 x 24.0 x 7.30

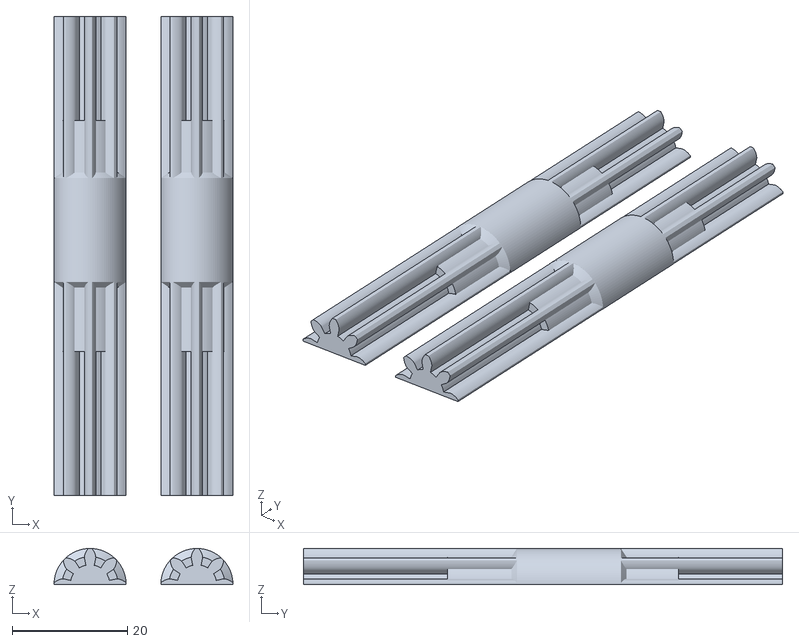
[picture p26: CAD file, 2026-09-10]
stl/dominator_shaft_short.stl
31.0 x 83.0 x 6.25

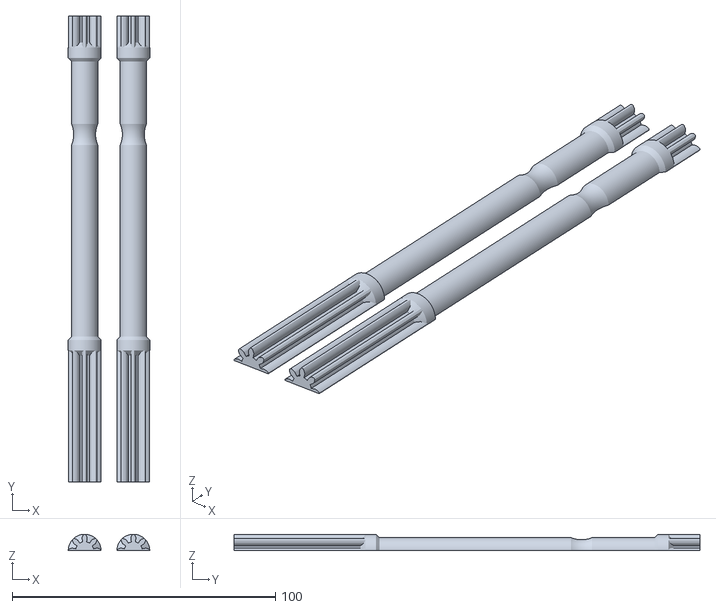
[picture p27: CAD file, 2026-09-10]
stl/dominator_shaft_long.stl
31.0 x 177.0 x 6.25

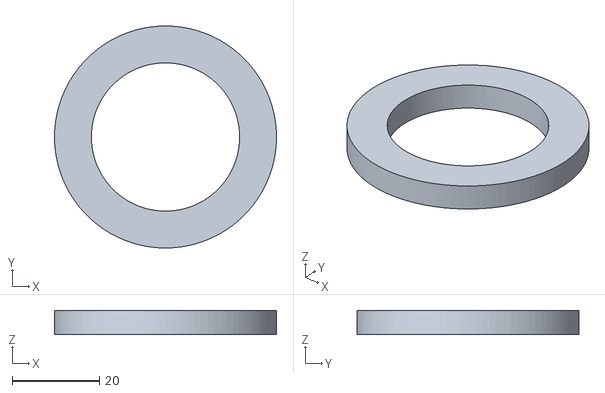
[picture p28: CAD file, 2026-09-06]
stl/dominator_gear_tooth_modifier.stl
51.0 x 51.0 x 5.60

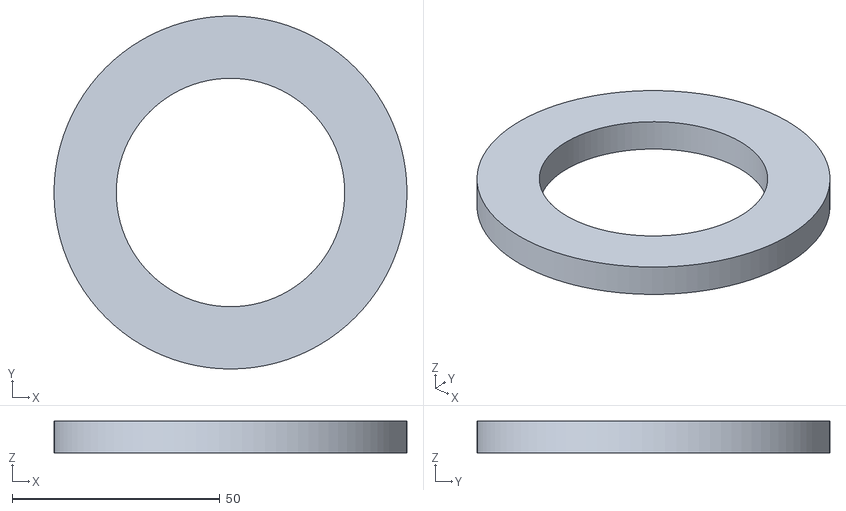
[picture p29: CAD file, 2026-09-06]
stl/dominator_rim_modifier.stl
85.0 x 85.0 x 7.60

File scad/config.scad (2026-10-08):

// config.scad - every tunable dimension for the Dominator cam + gear.
//
// Two printed pieces plus an optional washer:
//   cam   flat plate with the lobe outline, an integral hub rising
//         from it, and a socket in the top of the hub
//   gear  the 36 tooth ring gear with a matching plug underneath,
//         plugs into the socket and seats on the hub shoulder
// The steel pin runs through the bore of both.
//
// Sources: (owner) caliper readings on the worn part, (trace) measured from
// the owner's straight-down photo reference/cam_v2/own_cam_top_v2.jpg scaled to the
// 71 mm rim, (est) still an estimate.

include <lib/involute_gear.scad>

/* [Steel pin and bore] */
// Diameter of the steel pin the cam spins on. (owner) An earlier reading of
// the worn OEM bore gave 6.3; the v1 photo traces read it at 6.1 to 6.4. The
// pin itself is 6.00. The printed bore is pin + clearance.
pin_d = 6.00;
// Extra diameter so the cam spins freely on the pin. 0.3-0.4 typical for FDM.
bore_clearance = 0.4;
bore_d = pin_d + bore_clearance;

/* [Cam version] */
// The cam is moulded with a version number on both faces. The two versions
// share every dimension measured so far except the lobe pattern and the lobe
// height, so only those two are switched below. (owner)
cam_version = "v1"; // ["v1", "v2"]
// The OEM cam carries its number moulded into both faces. The printed cam
// engraves the same digit, taken from cam_version, so a printed part can be
// told apart from the other version once it is off the bed. 0 = no mark.
cam_version_number_size = 8;
// How deep the digit is cut into each face.
cam_version_number_depth = 0.5;
// Where the digit sits: radius from the centre, and angle around the plate.
// Must clear the hub and stay inside the trough circle.
cam_version_number_r = 22;
cam_version_number_angle = 270;
// The spline_clearance value (e.g. "0.05") is engraved the same way on the
// opposite side of the plate, so a cam sliced from a stale STL shows the
// clearance it was cut at. Same depth and radius as the digit. 0 = no mark.
cam_clearance_mark_size = 5;

/* [Cam plate] */
// Diameter of the trough circle of the rim, not across the lobes. (owner)
trough_d = 71;
// Plate thickness. This is the height of the lobe face the follower runs on. (owner)
plate_t = 6.6;
// How far each lobe protrudes beyond the trough circle, per version.
// (owner; v1 trace 4.15, v2 trace 4.5)
v1_lobe_height = 4;
v2_lobe_height = 5;
// Lobes as [start_deg, end_deg] at mid-height of the lobe, counter-clockwise
// seen from the gear side, 0 deg = +X. An optional third value overrides
// lobe_height for that lobe.
// v1 (trace) measured from reference/cam_v1/own_cam_top_v1.jpg, scaled by the
// cutting-mat grid and anchored to the 71.5 mm trough circle read off
// reference/cam_v1/own_cam_top_ruler_v1.jpg.
v1_lobes = [ [20.2, 70.1], [90.4, 131.5], [164, 210], [235, 284.9], [305.5, 355] ];
// v2 (trace) from reference/cam_v2/own_cam_top_v2.jpg. Re-measuring that photo
// with the v1 pipeline reproduces these widths to within 1.5 deg.
v2_lobes = [ [15, 65], [90, 133], [168.5, 209.5], [230, 279.5], [305, 354.5] ];
// The two differ in the narrow pair of lobes (v1 41.1 and 46.0 deg wide
// against v2 43 and 41) and in the largest trough (v1 32.5, v2 35.5 deg).
lobes       = cam_version == "v1" ? v1_lobes : v2_lobes;
lobe_height = cam_version == "v1" ? v1_lobe_height : v2_lobe_height;
// Rotate the whole lobe pattern (deg). Cosmetic, the gear is round.
lobe_rot = 0;
// Mirror the whole outline (lobe order and edge leans together). The photo
// used for the trace was taken looking at the non-gear side, and the owner
// confirmed the lean runs the other way when the part is held gear side up.
// Set false if a future trace is made from the gear side.
cam_mirror = true;
// Lean of the lobe edge faces from radial, deg. Positive = the face leans
// toward the middle of its lobe going outward. (trace) In the photo's view
// the clockwise edge leans 21 and the counter-clockwise edge 9; with
// cam_mirror = true the ramp face ends up on the counter-clockwise side
// when seen from the gear side. 0 = square radial steps.
ramp_lean = 21;
drop_lean = 9;
// Rounding of the outline corners (mm). 0 = sharp.
plate_corner_round = 0.6;

/* [Hub on the cam] */
// Hub outside diameter. The gear seats on the shoulder at its top. (est)
hub_d = 22;
// Hub height from the plate top to the gear underside. (owner)
hub_h = 14;

/* [Spline joint between hub and gear] */
// As in the OEM kit: the gear carries a plug on its underside, the top
// of the hub has a matching socket. The plug is an involute
// pinion profile. The gear seats on the flat shoulder of the hub around the
// socket, so the teeth only carry torque and do not locate the gear.
// Not an OEM dimension: the OEM gear and cam mate differently, so the spline
// is free design. (design) Sized to match the reduction gear pinion at
// 11 T / 16 mm so the project has one small tooth size rather than two nearly
// identical ones. Deliberately a SEPARATE parameter from rg_pinion_teeth /
// rg_pinion_od even though the values agree: the pinion is constrained by its
// mesh with the cam gear, this is constrained by the hub wall and by the press
// fit, and a change made for one must not silently alter the other.
spline_teeth = 11;
// Tip to tip diameter of the spline. Must be < hub_d, and
// leave at least 1.3 mm of wall between the bore and the tooth roots.
spline_od = 16;
// Tooth depth factors for the spline. Shallower than a real gear so the core
// stays thick around the bore.
spline_addendum = 0.9;
spline_dedendum = 0.9;
// Height of the plug under the gear = engagement depth in the hub.
plug_h = 5;
// The socket is this much deeper than the plug so the gear seats on the
// shoulder, not on the plug end.
socket_extra = 0.3;
// The whole of the joint's tolerance, applied as offset(delta = clearance) on
// the socket profile, so it is the gap normal to every flank, root and tip.
// It does not scale with tooth count or diameter.
// Printer dependent: run the fit test coupon (part = "fit_test") and set your
// own value. On the owner's Prusa MK4 in PETG the coupon found 0.05 best at
// 11 T / 16 mm, and 0.15 failed on both cam prints. A contributor's printer
// gripped best at 0.15. The value is engraved on the cam (clearance_mark).
spline_clearance = 0.05;
// Chamfer on the plug end to help it start into the socket (mm).
spline_lead_in = 0.6;

/* [Gear] */
// Tooth count, counted on the original by the owner. (owner)
gear_teeth = 36;
// Tip to tip diameter. Module is derived. (owner)
gear_od = 47;
gear_module = gear_module_from_od(gear_od, gear_teeth);
// Face width. (owner)
gear_thickness = 4.6;
gear_pressure_angle = 20;
// Backlash removed per tooth (mm). Negative makes the teeth fatter. Measured
// on the owner's gear-side photo (reference/cam_v2/own_gear_side_v2.jpg) the OEM teeth
// are about 0.1 of the pitch wider than a textbook involute at every depth,
// i.e. roughly 0.3 mm, though photo bloom inflates that a little. -0.2 is
// the estimate after allowing for bloom. If the mesh binds, move toward 0.
gear_backlash = -0.2;
// Tooth depth factors. The OEM teeth are stubbier than standard: measured
// working depth is about 2.4 mm against 2.78 for a standard 1.25 dedendum,
// so the dedendum is reduced to 1.0 (root diameter about 42 mm).
gear_addendum = 1.0;
gear_dedendum = 1.0;
// Chamfer on tooth faces. 0 to disable.
gear_chamfer = 0.4;
// Rounding of tooth tips (mm). The OEM tips are visibly rounded.
gear_tip_round = 0.3;

/* [Spacer washer] */
// Printed washer between the gearbox wall and the cam underside. 0 = none.
washer_t = 2;
washer_od = 16;

/* [Reduction gear (optional)] */
// One of the gearbox reduction gears: a ring plus a pinion on top. It is a
// different part from the cam gear and owns its ring dimensions outright.
// They happen to read the same today, but nothing forces them to move
// together: changing the cam gear must not silently reshape this part.
rg_ring_teeth = 36;        // (owner) same count as the cam gear, measured separately
rg_ring_od = 47;           // (owner)
rg_ring_thickness = 4.6;   // (owner)
rg_ring_module = gear_module_from_od(rg_ring_od, rg_ring_teeth);
// The pinion drives the cam gear, so its module must match the cam gear's.
// That is a mesh constraint, not a shared parameter: the value is set here and
// assembly.scad echoes a warning if the two modules drift apart.
// At 11 T / 16 mm the module is 1.2308 against the cam gear's 1.2368, a 0.5
// percent match. The earlier 12 T / 14.4 estimate was 17 percent out and
// could not have meshed at all.
rg_pinion_teeth = 11;      // (owner) counted; the photo suggested 11-12
rg_pinion_od = 16;         // (owner) across the tips
rg_pinion_h = 5;
// Raised plate between ring and pinion. 0 height = none. Real outline unknown.
rg_plate_d = 24;
rg_plate_h = 1.5;
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

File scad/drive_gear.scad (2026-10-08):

// drive_gear.scad - the gearbox drive gears.
// Module library: expects config.scad to be included by the caller.
// Origin: centre of the larger gear's underside. Z up.
//
// Drive gear 1 is a compound gear: a 26 tooth gear with a 19 tooth gear above
// it on the same axis, turning on the pin. Both halves share one module, taken
// from the outer gear, which is also the module of the drive shaft pinion the
// gear meshes with.
//
// Drive gear 2 is a single 23 tooth gear with a spacer boss on each face. It
// meshes with drive gear 1's 19 tooth half, so it takes its module from drive
// gear 1 rather than owning one.
//
// The OEM part has a web with material saving slots on one face and spokes on
// the other. The printed part is solid: the slots exist to save moulding
// material and shrinkage, neither of which applies here, and a solid body is
// stronger and simpler to slice.
//
// Printing: larger gear down, as exported. No supports. The bore runs right
// through, so the pin passes through both halves.

module drive_gear_1() {
    difference() {
        union() {
            // 26 tooth half, on the bed
            spur_gear(dg1_outer_teeth, dg1_module, dg1_outer_h,
                      pa = gear_pressure_angle, backlash = ds_tooth_backlash, bore = 0,
                      addendum = dg_addendum, dedendum = dg_dedendum,
                      tip_round = gear_tip_round, chamfer = gear_chamfer);
            // 19 tooth half above it
            translate([0, 0, dg1_outer_h - eps])
                spur_gear(dg1_inner_teeth, dg1_module, dg1_inner_h + eps,
                          pa = gear_pressure_angle, backlash = ds_tooth_backlash, bore = 0,
                          addendum = dg_addendum, dedendum = dg_dedendum,
                          tip_round = gear_tip_round, chamfer = gear_chamfer);
        }
        translate([0, 0, -1])
            cylinder(h = dg1_outer_h + dg1_inner_h + 2, d = bore_d, $fn = 64);
    }
}

// Total height of drive gear 1, for the console echo and for anything stacking
// against it.
function dg1_height() = dg1_outer_h + dg1_inner_h;

// Drive gear 2: one gear with a spacer boss on each face. The bosses stand the
// gear off its neighbours on the pin, so they are part of the gear and not
// separate washers.
// Origin: the underside of the lower spacer. Z up.
module drive_gear_2() {
    difference() {
        union() {
            translate([0, 0, dg2_spacer_h - eps])
                spur_gear(dg2_teeth, dg2_module, dg2_h + eps,
                          pa = gear_pressure_angle, backlash = ds_tooth_backlash, bore = 0,
                          addendum = dg_addendum, dedendum = dg_dedendum,
                          tip_round = gear_tip_round, chamfer = gear_chamfer);
            // spacer below and above
            cylinder(h = dg2_spacer_h + eps, d = dg2_spacer_d);
            translate([0, 0, dg2_spacer_h + dg2_h - eps])
                cylinder(h = dg2_spacer_h + eps, d = dg2_spacer_d);
        }
        translate([0, 0, -1])
            cylinder(h = dg2_height() + 2, d = bore_d, $fn = 64);
    }
}

// Total height of drive gear 2, spacers included.
function dg2_height() = dg2_h + 2 * dg2_spacer_h;

// Drive gear 3: a 26 tooth gear with a boss on each face and an 8 lobe socket
// in each end for the drive shafts. No bore: a solid wall separates the
// sockets, and the gear is carried by the shafts rather than the pin.
// Origin: the end face of the short boss. Z up.
function dg3_height() = dg3_short_h + dg3_gear_h + dg3_long_h;
// Height of the cut plane, at mid-height of the gear.
function dg3_cut_z() = dg3_short_h + dg3_gear_h / 2;

// The drive shaft pinion profile grown by the socket clearance. Built from the
// same values the shaft uses, so a change to the shaft moves the socket with it.
module dg3_socket_2d() {
    offset(delta = dg3_socket_clearance)
        gear_2d(8, gear_module_from_od(ds_gear_od, 8), pa = 20, backlash = ds_tooth_backlash);
}

module drive_gear_3_whole() {
    H = dg3_height();
    difference() {
        union() {
            cylinder(h = H, d = dg3_boss_d);
            translate([0, 0, dg3_short_h])
                spur_gear(dg3_teeth, dg3_module, dg3_gear_h,
                          pa = gear_pressure_angle, backlash = ds_tooth_backlash, bore = 0,
                          addendum = dg_addendum, dedendum = dg_dedendum,
                          tip_round = gear_tip_round, chamfer = gear_chamfer);
        }
        // short shaft socket, open at z = 0
        translate([0, 0, -1]) linear_extrude(dg3_short_socket + 1) dg3_socket_2d();
        // long shaft socket, open at the top
        translate([0, 0, H - dg3_long_socket]) linear_extrude(dg3_long_socket + 1) dg3_socket_2d();
    }
}

// Dowel holes centred on the cut plane, reaching ds_dowel_depth into each half.
module dg3_dowels() {
    for (i = [0 : dg3_dowel_count - 1])
        rotate(i * 360 / dg3_dowel_count + 45)
            translate([dg3_dowel_r, 0, dg3_cut_z() - ds_dowel_depth])
                cylinder(h = 2 * ds_dowel_depth, d = ds_dowel_d + ds_dowel_clearance, $fn = 24);
}

// Printable layout. One piece (default): standing on the short boss; the gear
// needs supports under its overhang, and the wall bridges the short socket. Split: both halves stand on
// their cut faces, side by side, and the dowel holes open upward.
module drive_gear_3() {
    zc = dg3_cut_z();
    H = dg3_height();
    big = dg3_module * (dg3_teeth + 2) + 10;
    if (!dg3_split) {
        drive_gear_3_whole();
    } else {
        // half A: short boss and the lower half of the gear, short boss up
        translate([0, 0, zc]) mirror([0, 0, 1])
            difference() {
                drive_gear_3_whole();
                dg3_dowels();
                translate([-big / 2, -big / 2, zc]) cube([big, big, H]);
            }
        // half B: upper half of the gear and the long boss, long boss up
        translate([dg3_module * (dg3_teeth + 2) + 6, 0, -zc])
            difference() {
                drive_gear_3_whole();
                dg3_dowels();
                translate([-big / 2, -big / 2, -1]) cube([big, big, zc + 1]);
            }
    }
}

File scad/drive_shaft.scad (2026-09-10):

// drive_shaft.scad - Dominator gearbox drive shafts as one parametric model,
// designed to print lying down for strength.
// Module library: expects config.scad to be included by the caller.
//
// Construction, along Z from the "A" end at z = 0:
//   an 8 tooth involute pinion profile runs the FULL length of the shaft;
//   round body sections are unioned over it where the body is plain, with a
//   cone at each end of every body section that tapers into the tooth roots,
//   so there is no sharp step where the gear meets the body (the break point
//   on vertical prints);
//   a core cylinder fills the tooth roots in the "lobed" sections;
//   a circular arc groove is cut where specified;
//   a full length core channel takes a steel rod, and dowel holes on the
//   split face take short pieces of filament.
//
// Printing: the shaft is split lengthwise into two identical halves. Each is
// printed with its flat face on the bed, so the layers run along the shaft
// and the teeth are printed on their sides. The two halves are glued around
// the rod with the dowels for alignment. Set ds_split = false for a whole
// shaft (vertical print, weak at the steps).
//
// A shaft spec is a list of named fields, see ds_long / ds_short in config.

function ds_get(s, k, dflt = undef) =
    let(i = search([k], s, 1)[0]) (i == [] ? dflt : s[i][1]);

module drive_shaft_solid(s) {
    L        = ds_get(s, "length");
    teeth    = ds_get(s, "teeth", 8);
    od       = ds_get(s, "gear_od", ds_gear_od);
    body_d   = ds_get(s, "body_d", ds_body_d);
    body     = ds_get(s, "body", []);
    lobed    = ds_get(s, "lobed", []);
    core_d   = ds_get(s, "lobe_core_d", 0);
    groove   = ds_get(s, "groove", []);
    mod      = gear_module_from_od(od, teeth);
    rr       = gear_root_radius(teeth, mod);
    fl       = ds_step_fillet;
    difference() {
        union() {
            // full length pinion. ds_split_at = "gaps" rotates it so a tooth
            // gap lies on the split plane (each half carries whole teeth, the
            // glue line is in the gaps); "teeth" puts tooth centres on the
            // split plane (half teeth lie flat on the bed, wider footprint).
            rotate(ds_split_at == "gaps" ? 180 / teeth : 0)
                spur_gear(teeth, mod, L, pa = 20, backlash = ds_tooth_backlash, bore = 0);
            for (b = body) {
                translate([0, 0, b[0]]) cylinder(h = b[1] - b[0], d = body_d);
                // root fillets: cones from the body down into the teeth
                if (fl > 0) {
                    if (b[0] > 0)
                        translate([0, 0, b[0] - fl]) cylinder(h = fl + eps, r1 = rr, r2 = body_d / 2);
                    if (b[1] < L)
                        translate([0, 0, b[1] - eps]) cylinder(h = fl + eps, r1 = body_d / 2, r2 = rr);
                }
            }
            if (core_d > 0) for (b = lobed) translate([0, 0, b[0]]) cylinder(h = b[1] - b[0], d = core_d);
        }
        // body relief: turn the smooth body down to ds_relief_d over each
        // [z0, z1] in the shaft's "relief" list, with 45 degree transitions
        for (rg = ds_get(s, "relief", [])) if (ds_relief_d > 0 && ds_relief_d < body_d) {
            rd = ds_relief_d / 2; bd = body_d / 2; t = bd - rd;
            rotate_extrude($fn = 96)
                polygon([ [rd, rg[0] + t], [rd, rg[1] - t], [bd, rg[1]], [bd + 1, rg[1]],
                          [bd + 1, rg[0]], [bd, rg[0]] ]);
        }
        if (len(groove) == 4) {
            zc = groove[0]; w = groove[1]; dpt = groove[2]; ar = groove[3];
            rb = body_d / 2 - dpt;
            translate([0, 0, zc])
                rotate_extrude($fn = 96)
                    intersection() {
                        translate([rb + ar, 0]) circle(r = ar, $fn = 180);
                        translate([rb, -w / 2]) square([body_d, w]);
                    }
        }
        // steel rod channel, full length
        if (ds_rod_d > 0)
            translate([0, 0, -1]) cylinder(h = L + 2, d = ds_rod_d + ds_rod_clearance, $fn = 48);
    }
}

// Dowel holes on the split face, at the z positions in the shaft's "dowels"
// list. With ds_dowel_offset = 0 they sit on the axis, one per position,
// which works everywhere along the shaft: on the axis the material above the
// flat face is the full radius, even in the gear sections. With an offset
// they come in pairs at +x and -x so identical halves still register.
module ds_dowel_holes(s) {
    for (z = ds_get(s, "dowels", []))
        for (sx = (ds_dowel_offset > 0 ? [-1, 1] : [0]))
            translate([sx * ds_dowel_offset, 0, z])
                rotate([90, 0, 0]) cylinder(h = 2 * ds_dowel_depth, d = ds_dowel_d + ds_dowel_clearance, center = true, $fn = 24);
}

// One half, cut on the plane y = 0, laid flat with the cut face on z = 0 and
// the shaft axis along +Y.
module drive_shaft_half(s) {
    L = ds_get(s, "length"); R = ds_body_d / 2 + 2;
    rotate([90, 0, 0])
        difference() {
            drive_shaft_solid(s);
            translate([-R, -2 * R, -1]) cube([2 * R, 2 * R, L + 2]);   // remove y < 0
            ds_dowel_holes(s);
        }
}

// Both halves side by side, ready to print.
module drive_shaft_print(s) {
    R = ds_body_d / 2;
    translate([-R - 3, 0, 0]) drive_shaft_half(s);
    translate([ R + 3, 0, 0]) drive_shaft_half(s);
}

module drive_shaft(s) {
    if (ds_split) drive_shaft_print(s); else drive_shaft_solid(s);
}

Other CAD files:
stl/dominator_follower.stl
stl/dominator_washer.stl
stl/dominator_cam_v1.stl
scad/assembly.scad
scad/cam.scad
scad/cam_gear.scad
scad/fit_test.scad
scad/reduction_gear.scad

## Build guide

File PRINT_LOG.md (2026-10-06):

# Print log

One entry per physical print. Records the config values used, what was observed, and what changed for the next print. Settings not listed were at the defaults in `scad/config.scad` at that commit.

## Print 1, 2026-09-05

Reconstructed from the session history; the repo had no commits yet. This is the config as it stood when the print was reported, which was after the outline mirror and the pin measurement had gone in. If the print actually started earlier, the differences would be `cam_mirror = false`, `pin_d = 6.35` and `hub_d = 18`.

Design: flat cam plate with integral shaft and toothed pocket, separate gear with toothed boss, spacer washer.

| Parameter | Value |
|---|---|
| `pin_d` | 6.3 |
| `bore_clearance` | 0.4 (bore 6.7) |
| `cam_od` | 71 |
| `cam_t` | 6.6 |
| `cam_ear_out` | 4 |
| `cam_bumps` | [15, 65], [90, 133], [168.5, 209.5], [230, 279.5], [305, 354.5] |
| `cam_bump_rot` | 0 |
| `cam_mirror` | true |
| `cam_lean_start` / `cam_lean_end` | 21 / 9 |
| `cam_outline_round` | 0.6 |
| `hub_d` | 22 |
| `hub_h` | 14 |
| `spline_teeth` | 12 |
| `spline_od` | 14 |
| `spline_addendum` / `spline_dedendum` | 0.9 / 0.9 |
| `spline_boss_h` | 5 |
| `spline_pocket_extra` | 0.3 |
| `spline_clearance` | 0.15 |
| `spline_lead_in` | 0.6 |
| `gear_teeth` | 36 |
| `gear_od` | 47 (module 1.237) |
| `gear_thickness` | 4.6 |
| `gear_pressure_angle` | 20 |
| `gear_backlash` | 0.15 |
| tooth depth | standard, addendum 1.0, dedendum 1.25 (not yet parameters) |
| `gear_chamfer` | 0.4 |
| `gear_tip_round` | 0.15 |
| `washer_t` / `washer_od` | 2 / 16 |

Stack: washer 2 + plate 6.6 + shaft 14 + gear 4.6 = 27.2 mm wall to gear top.

Slicer settings (PrusaSlicer): PETG, 0.2 mm layers, 2 perimeters, 15 percent grid infill.

Observed:

- Overall fit and appearance good for a first attempt.
- Play between the gear's toothed boss and the shaft pocket.
- Gear teeth thinner than the original.

Changes made for print 2:

- `spline_clearance` 0.15 to 0.05.
- `gear_backlash` 0.15 to -0.2 (teeth about 0.35 mm fatter in total).
- `gear_dedendum` 1.25 to 1.0 (root diameter about 42 mm, stubbier teeth like the OEM).
- `gear_tip_round` 0.15 to 0.3.
- `gear_addendum` and `gear_dedendum` added as parameters.
- Tooth count briefly changed to 35 from a photo estimate, then reverted to 36 after counting.

## Rename, 2026-09-06

Parameters were renamed to match the glossary in `CONTEXT.md`. Shape verified identical before and after. Print 1 above uses the old names.

| Old | New |
|---|---|
| `cam_od` | `trough_d` |
| `cam_t` | `plate_t` |
| `cam_ear_out` | `lobe_height` |
| `cam_bumps` | `lobes` |
| `cam_bump_rot` | `lobe_rot` |
| `cam_lean_start` | `ramp_lean` |
| `cam_lean_end` | `drop_lean` |
| `cam_outline_round` | `plate_corner_round` |
| `spline_boss_h` | `plug_h` |
| `spline_pocket_extra` | `socket_extra` |

## Print 2, 2026-09-28

Cam v2 and gear. Meant to test `spline_clearance = 0.05` on the owner's printer, but the cam was sliced from `stl/dominator_cam_v2.stl` before it was re-exported in 9c4f0b4, so it is the export from 120f812 with the socket cut at 0.15. The gear is from 5ddb780; its plug is nominal and does not depend on the clearance. So this print tests 0.15 on the owner's printer at the current spline (11 teeth, 16 mm tip to tip), and checks tooth solidity.

| Parameter | Value |
|---|---|
| `cam_version` | v2 (lobe height 5) |
| `pin_d` / `bore_clearance` | 6.00 / 0.4 (bore 6.4) |
| `spline_teeth` / `spline_od` | 11 / 16 |
| `spline_clearance` | 0.15 in the printed socket (config at the time said 0.05) |

Slicer settings: Prusa MK4, PETG, 6 perimeters.

Observed:

- The spline joint failed at 0.15.

Followed up with a fit test coupon on the owner's printer, below.

## Spline fit test coupon, owner's printer, after print 2

`part = "fit_test"` at the current spline (11 teeth, 16 mm tip to tip), sockets at `spline_clearance` 0, 0.05, 0.10 and 0.15 with loose plugs at nominal. Printed on the owner's Prusa MK4 after print 2 failed at 0.15.

Observed:

- **0.05 works** on the owner's printer.

Changes made: none; `spline_clearance` was already 0.05. The coupon cuts its sockets with the same `socket_cut` module as the cam, so it is taken as enough evidence without a 0.05 cam print. The cam and gear at 0.05 have not been printed yet.

This settles the open question in the contributor's coupon entry below: the owner's printer wants 0.05 and the contributor's printer 0.15, so the difference is the printer, not the spline size or the part geometry.

## Spline fit test coupon, 2026-09-22

`part = "fit_test"`, printed at the spline as it now stands: 11 teeth, 16 mm
tip to tip, `spline_addendum` / `spline_dedendum` 0.9. Four sockets at
`spline_clearance` 0, 0.05, 0.10 and 0.15 with loose plugs at nominal.

Printed on a contributor's printer, not the owner's; settings not recorded.

Observed:

- **0.15 is the best fit** on that printer.

Changes made:

- `spline_clearance` 0.05 to 0.15, later reverted to 0.05 for the owner's printer (see print 2).

Open question: print 1 used 0.15 and was reported as having play. The two
disagree. The differences between them are the spline size (12 T / 14 mm then,
11 T / 16 mm now), the printer settings (print 1 was PETG, 0.2 mm layers, 2
perimeters, 15 percent infill; the coupon's settings are not recorded), and the
part geometry the joint was printed as part of (a 47 mm gear and a 71 mm cam
then, small pucks now). Which of those accounts for it is not known. The real
parts should be printed and checked before the 0.15 is trusted for good.

Resolved: the owner's coupon after print 2 found 0.05 best on the owner's printer, so the two results reflect different printers.

## Drive gear 2, print 1, 2026-10-06

`part = "drive_gear_2"` as committed: 23 teeth, tip diameter 31.25 mm, module
1.25, gear body 15 mm, a 1.5 mm spacer at 14 mm diameter on each face, total
18 mm, bore 6.4 mm. Printed on one spacer, no supports.

Observed:

- Correct. The gear meshes and the dimensions are right.

This settles two open questions. The tip diameter of 31.25 is right and the
owner's caliper reading of 30 was the odd tooth count reading it was taken to
be: 23 is odd, so no tooth lies opposite another and a caliper cannot span tip
to tip. The gear body of 15 mm is also right, against a trace of the side
photograph that suggested 17 to 19; a photograph read along the axis of a part
lying on its side is not reliable for that dimension.

No config changes.

## Slicing note

How to make the contact regions solid without a fully solid part is written up in `SLICING.md`: Fill density 100 percent on the modifier meshes, a modest perimeter count on the object itself.

## Long drive shaft, print 1, 2026-09-10

Config as committed in 2283e47: two halves split through tooth centres, gear OD 12.45, root fillets 2, body relieved to 10 mm, single row of axis dowel holes at 4, 10, 20, 35, 60, 90, 120, 131, 145, 160, 173.

Assembly: dowels of 1.75 mm filament, halves glued with PVC pipe cement.

Observed:

- Dowels align the halves very well.
- Joint is solid; the finished shaft is strong and somewhat flexible.
- Not yet tested in the cleaner.

Slicer settings: not recorded, add if known.

No config changes.

## Drive gear 1, print 1, 2026-10-06

`part = "drive_gear_1"` as committed: a 26 tooth gear 10 mm wide with a 19
tooth gear 11 mm wide above it, tip diameters 35 and 26.25 mm, module 1.25,
total 21 mm, bore 6.4 mm, solid body. Printed with the 26 tooth gear on the
bed, no supports. Slicer settings not recorded; add them if known.

Observed:

- Correct. The gear meshes and the dimensions are right.

This confirms three things that were derived rather than measured. The module
of 1.25, taken from the 26 tooth gear because 26 is even and a caliper can span
tip to tip. The 19 tooth tip diameter of 26.25, calculated from that module
against a caliper reading of 25 to 26, which read low because 19 is odd. And
the bore, which is `bore_d` and therefore the same hole as the cam: the drive
gears run on the same pin.

The two face widths are the owner's corrected values, 10 mm for the 26 tooth
gear and 11 mm for the 19 tooth gear. They were briefly entered the other way
round.

No config changes.

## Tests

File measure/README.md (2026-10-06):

# Measurement guide

The cam is moulded with a version number on both faces. The owner has one of
each, and the two differ, so the measurement sheets are kept apart:

| Folder | Part |
|---|---|
| [`cam_v1/`](cam_v1/) | the cam stamped 1 |
| [`cam_v2/`](cam_v2/) | the cam stamped 2 |

Each folder holds annotated photos with lettered callouts and a README listing
what each letter means and what is still to be measured. Every callout names a
parameter in `scad/config.scad` using the vocabulary in `CONTEXT.md`.

## What differs between the versions

Only two parameters, both on the cam plate:

| | v1 | v2 |
|---|---|---|
| `lobe_height` | 4 mm | 5 mm |
| `lobes` | 20.2-70.1, 90.4-131.5, 164-210, 235-284.9, 305.5-355 | 15-65, 90-133, 168.5-209.5, 230-279.5, 305-354.5 |

Everything else measured so far reads the same on both: trough circle 71 mm,
plate 6.6 mm, hub 22 x 14 mm, gear 36 T at 47 mm, bore for a 6.0 mm pin.

## How the traces were made

The outline is segmented from the owner's straight-down photograph, sampled as
a radius-versus-angle profile about the part's centroid, and scaled by the
cutting-mat grid anchored to the trough circle read off the ruler photograph.

Two cautions learned the hard way:

- **Parallax.** A ruler resting on the part sits about 12 mm closer to the lens
  than the mat it lies on, which magnifies it by roughly 4 percent at phone
  range. Scale from a feature in the same plane as the thing being measured.
- **EXIF rotation.** Some of the photographs carry an orientation flag. Image
  libraries that ignore it read the array unrotated, which silently rotates
  every angle measured from it.

Running this pipeline over the v2 photograph reproduces the v2 lobe widths
already in the config to within 1.5 degrees. That is the accuracy these traced
angles should be trusted to; anything finer needs calipers.

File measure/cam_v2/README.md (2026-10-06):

# Cam v2 measurements

The cam stamped **2** on both faces. Source photographs are in
`reference/cam_v2/`. This is the version the project was originally built
around, so most values in `config.scad` came from here.

## 1_cam_top_view_v2.png

Traced from `reference/cam_v2/own_cam_top_v2.jpg`, scaled by the owner's 71 mm
rim reading.

| Letter | Parameter | What it is | Value |
|---|---|---|---|
| A | `trough_d` | Diameter of the trough circle, rim outside face to outside face where there is no lobe | 71, owner's calipers |
| C | `lobe_height` | How far a lobe stands out past the trough circle | 5, trace 4.5 |
| E | `pin_d` | Bore, or the steel pin if you can measure it cleanly | photo reads 6.2, pin set 6.0 |
| 1 to 5 | `v2_lobes` | Start and end angle of each lobe, at mid-height | done, see below |

Lobe angles, counter-clockwise, 0 degrees to the right:

| Lobe | Start | End | Width | Trough after it |
|---|---|---|---|---|
| 1 | 15 | 65 | 50 | 25 |
| 2 | 90 | 133 | 43 | 35.5 |
| 3 | 168.5 | 209.5 | 41 | 20.5 |
| 4 | 230 | 279.5 | 49.5 | 25.5 |
| 5 | 305 | 354.5 | 49.5 | 20.5 |

Re-tracing this photograph with the v1 pipeline reproduces these widths to
within 1.5 degrees, which is what sets the confidence in both versions.

The photograph is of the cam side, so the model mirrors the outline
(`cam_mirror = true`). Confirmed against the gear-side photograph
`reference/cam_v2/own_gear_side_v2.jpg`, which shows the ramp face on the
counter-clockwise edge and the mirrored trough sequence.

## 5_lobe_edge_lean_v2.png

Zoom on lobe 2 with radial reference lines. The edge faces are straight but not
radial: seen from the cam side with 0 degrees to the right, the clockwise edge
of each lobe leans about 21 degrees toward the middle of the lobe as it goes
outward, and the counter-clockwise edge about 9 degrees the same way. All five
lobes agree within a degree. These are `ramp_lean` and `drop_lean`; the `lobes`
angles are taken at mid-height so the lean pivots about that point.

## 7_top_lobe_faces_v2.png

The lobe faces seen from above, used to confirm which face is the ramp and
which the drop.

## Gear

From `reference/cam_v2/own_gear_side_v2.jpg`:

| Parameter | Value | How |
|---|---|---|
| `gear_teeth` | 36 | counted by the owner |
| `gear_od` | 47 | calipers |
| `gear_thickness` | 4.6 | calipers |
| `gear_backlash` | -0.2 | teeth read about 0.1 of the pitch wider than a textbook involute at every depth, allowing for photo bloom |
| `gear_dedendum` | 1.0 | working depth about 2.4 mm against 2.78 for a standard 1.25 dedendum |

## Still to measure

| Parameter | Note |
|---|---|
| `washer_t` | Gearbox wall to the underside of the cam. Never measured. |
| Stack check | `washer_t` + `plate_t` + `hub_h` + `gear_thickness` should equal the wall-to-gear-top distance. The console echo prints the total. |

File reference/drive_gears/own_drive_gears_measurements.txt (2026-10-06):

drive_gear_1
drive_gear_1_outer_diameter = 35
drive_gear_1_outer_teeth_count = 26
drive_gear_1_outer_height = 10
drive_gear_1_inner_diameter = 25
drive_gear_1_inner_teeth_count = 19
drive_gear_1_inner_height = 11
drive_gear_1_total_height = 21

drive_gear_2
drive_gear_2_diameter = 30
drive_gear_2_teeth_count = 23
drive_gear_2_height = 15
drive_gear_2_height_spacer = 1.5mm (one on either side)

drive_gear_3
drive_gear_3_teeth_count = 26
drive_gear_3_diameter = 35
drive_gear_3_shaft_diameter = 18
drive_gear_3_total_height = 30
drive_gear_3_gear_height = 11
drive_gear_3_shaft_height = 14
drive_gear_3_shaft_height_short = 5

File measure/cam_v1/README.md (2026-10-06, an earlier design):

# Cam v1 measurements

The cam stamped **1** on both faces. Source photographs are in
`reference/cam_v1/`.

## 1_cam_top_view_v1.png

Traced from `reference/cam_v1/own_cam_top_v1.jpg`, scaled by the cutting-mat
grid and anchored to the 71.5 mm trough circle read off
`reference/cam_v1/own_cam_top_ruler_v1.jpg`.

| Letter | Parameter | What it is | Value |
|---|---|---|---|
| A | `trough_d` | Diameter of the trough circle, rim outside face to outside face where there is no lobe | 71.5 traced, config 71 |
| C | `lobe_height` | How far a lobe stands out past the trough circle | 4, trace 4.15 |
| E | `pin_d` | Bore, or the steel pin if you can measure it cleanly | bore 6.1-6.4, pin set 6.0 |
| 1 to 5 | `v1_lobes` | Start and end angle of each lobe, at mid-height | done, see below |

Lobe angles as traced, counter-clockwise, 0 degrees to the right:

| Lobe | Start | End | Width | Trough after it |
|---|---|---|---|---|
| 1 | 20.2 | 70.1 | 49.9 | 20.3 |
| 2 | 90.4 | 131.5 | 41.1 | 32.5 |
| 3 | 164 | 210 | 46.0 | 25.0 |
| 4 | 235 | 284.9 | 49.9 | 20.6 |
| 5 | 305.5 | 355 | 49.5 | 25.2 |

The photograph is of the cam side, not the gear side, so the model mirrors the
whole outline (`cam_mirror = true`), which flips the lobe order and the two
edge leans together.

## Against v2

| | v1 | v2 |
|---|---|---|
| Lobe 2 width | 41.1 | 43 |
| Lobe 3 width | 46.0 | 41 |
| Largest trough | 32.5 | 35.5 |
| `lobe_height` | 4 | 5 |
| Outer span across the crests | 79 | 81 |

Lobes 1, 4 and 5 are the same width on both within a degree.

## Still to measure on v1

Calipers needed; none of these can be read from the photographs to better than
the trace accuracy of about 1.5 degrees and half a millimetre.

| Parameter | Note |
|---|---|
| `plate_t` | Plate thickness. v2 reads 6.6. |
| `hub_h`, `hub_d` | Hub height and diameter. v2 reads 14 and 22. |
| `gear_od`, `gear_thickness` | The gear is a separate part; v2 reads 47 and 4.6, and the v1 photo trace agrees on the tooth count. |
| `washer_t` | Gearbox wall to the underside of the cam. Never measured on either version. |
| `ramp_lean`, `drop_lean` | Edge leans. Taken from the v2 trace (21 and 9 degrees) and assumed to carry over; not yet checked on v1. |

## Not in the photographs

- Whether the edge leans really are the same as v2. The lobe widths differ, so
  the faces may too.
- The direction the cam turns in the gearbox. Observed on v2 as
  counter-clockwise seen from the gear side, ramp face meeting the follower
  first; assumed the same for v1.

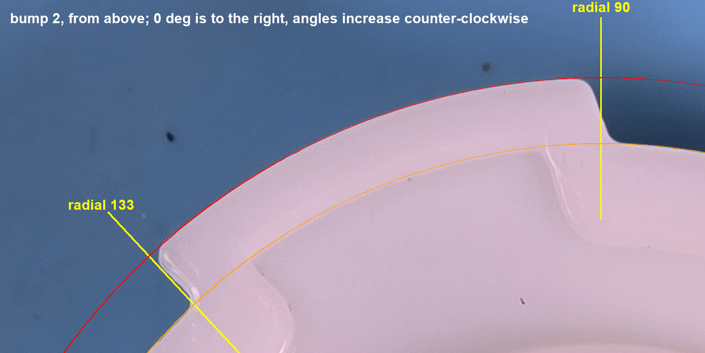
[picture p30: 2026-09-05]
measure/cam_v2/5_lobe_edge_lean_v2.png

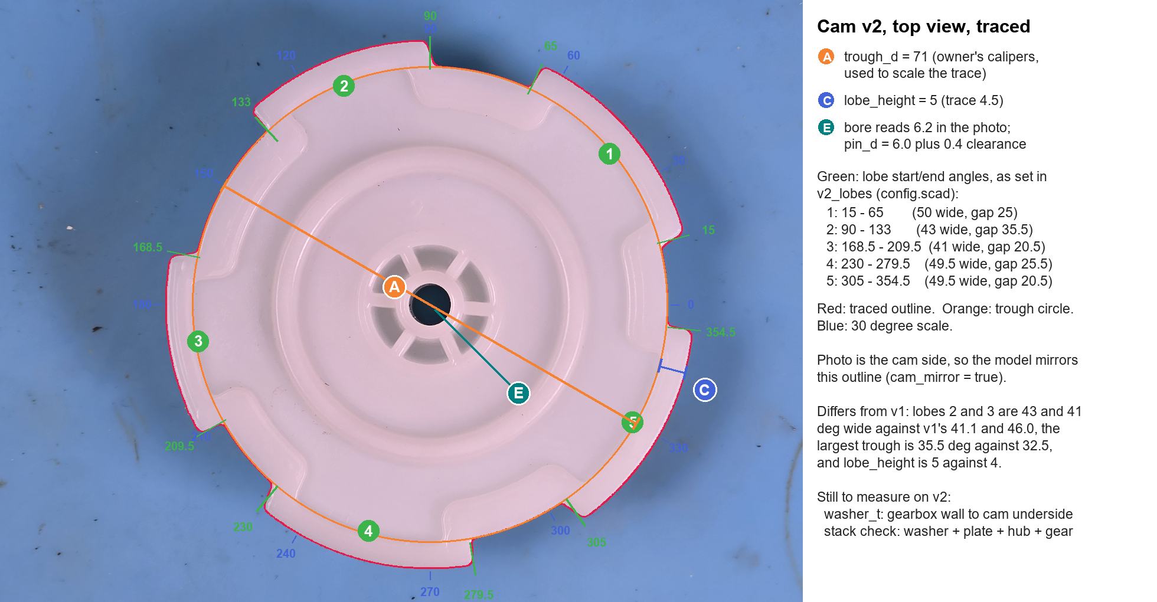
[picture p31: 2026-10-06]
measure/cam_v2/1_cam_top_view_v2.png

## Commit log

2026-09-05 Dominator cam and gear: flat cam with splined shaft, separate gear, washer
    Parametric OpenSCAD replacement for the Kreepy Krauly Dominator steering cam.
    Cam outline traced from the owner's photos (five bumps, leaning edges,
    mirrored to the gear side), 36 tooth gear with fattened stubby teeth,
    toothed boss and pocket joint, spacer washer, optional follower gear.
    Includes involute gear library, render script, STL exports, renders and
    measurement sheets. Internet-sourced reference photos are not tracked.
    [assembly.scad, cam.scad, cam_gear.scad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]
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2026-09-06 Rename parameters and wording to match the CONTEXT.md glossary
    lobe, trough, trough_d, plate_t, lobe_height, ramp_lean, drop_lean,
    plug, socket, hub, shoulder, stack height. Shape verified identical
    before and after (vertex sets of all exported STLs match).
    [assembly.scad, cam.scad, cam_gear.scad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]
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2026-09-06 Slicer modifiers: cam rim ring, gear tooth band, gear plug; infill only, perimeters on the object
    [assembly.scad, cam.scad, cam_gear.scad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]
2026-09-06 Rename follower gear to reduction gear; ring derived from the cam gear
    Follower is reserved for the gearbox part that rides on the lobes.
    The reduction gear ring now uses gear_teeth, gear_od and gear_thickness
    directly. Glossary updated with reduction gear and pinion.
    [assembly.scad, config.scad, dominator_reduction_gear.stl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]
2026-09-10 Add drive shafts: split halves for flat printing, dowel aligned, relieved body
    One drive_shaft() module with presets ds_long (177 mm) and ds_short (83 mm).
    8 tooth pinion profile full length, gear OD 12.45, root fillets at each
    body step, long body relieved to 10 mm between gear seats, split through
    tooth centres into two identical halves printed flat, single row of axial
    dowel holes for filament pins. Also adds continuation.md session notes.
    [assembly.scad, config.scad, dominator_shaft_long.stl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]
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2026-09-22 Add cam v1/v2 versioning; decouple reduction gear; spline 11 T at 0.15
    The cam is moulded with a version number on both faces and the owner has one
    of each. They differ in the lobe pattern and the lobe height only, so
    cam_version selects between v1_lobes / v2_lobes and v1_lobe_height /
    v2_lobe_height; everything else stays shared. Only the cam STL carries a
    _v1 / _v2 suffix. The rim modifier is sized from the taller lobes so one file
    serves both. The printed cam engraves its version digit into both faces.
    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
    [assembly.scad, cam.scad, config.scad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]
2026-09-22 Simplify fit test coupon and rename measures
    Rename the measurement folders to `cam_v1` and `cam_v2` so they match the reference photo layout, updating the related README and continuation notes and refreshing the v2 top-view asset. Rework the fit test coupon to remove the loose plugs and make it a socket-only plate meant to be tested with an actual printed gear, then regenerate the preview image and fit-test STL to match.
    [dominator_fit_test.stl, fit_test.scad]
2026-09-28 Spline clearance back to 0.05 for the owner's printer; re-export cam v1 and gear
    The 0.15 from the fit test coupon was measured on a contributor's printer.
    On the owner's printer 0.15 had play, so 0.05 is restored and this cam and
    gear pair is exported to test it at the 11 T / 16 mm spline.
    [config.scad, dominator_cam_v1.stl, dominator_gear.stl]
2026-09-28 Fix render.ps1 quoting under pwsh 7.3+; log print 2
    pwsh 7.3+ escapes quotes in native arguments itself, so the pre-escaped
    \" reached OpenSCAD literally and the -D assignment failed to parse. The
    escaping now depends on PSNativeCommandArgumentPassing; tested in both
    pwsh 7.6 and Windows PowerShell 5.1.
    Print log: record print 2 (0.05 clearance, PETG, 6 perimeters) and note
    that the fit test coupon was printed on a contributor's printer.
2026-09-28 Re-export cam v2 at spline_clearance 0.05
    Full re-render of every part. Only the v2 cam changed in geometry (its
    socket was still cut at 0.15); the other STLs came out identical apart
    from facet order and are left as committed.
    [dominator_cam_v2.stl]
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2026-09-28 Add cam socket modifier for a solid hub around the spline socket
    The gear plug modifier is sized for the gear (z -0.5 to 10.1) and cannot
    reach the cam socket at z 15.3 to 20.6. The new cam_socket_modifier covers
    the full hub width from socket_band (1.5 mm) below the socket floor to just
    above the hub top. Version independent, so one STL serves both cams.
    [assembly.scad, cam.scad, config.scad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]
2026-09-29 Engrave spline_clearance on the cam, opposite the version digit
    A cam sliced from a stale STL now shows the clearance its socket was cut
    at, both in the slicer and on the printed part. The version digit and the
    new mark share one face_mark helper. cam_clearance_mark_size (5) sets the
    text size; 0 turns it off.
    [cam.scad, config.scad, dominator_cam_v1.stl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]
2026-09-29 Log print 2 failure at 0.15 and owner's fit test coupon at 0.05
    The owner's coupon found 0.05 best at 11 T / 16 mm, which resolves the
    disagreement with the contributor's coupon (0.15): it is the printer.
    Clearance comments in config.scad and fit_test.scad updated to match.
    [config.scad, fit_test.scad]
2026-09-29 Rewrite README in Simplified Technical English
    New layout: how the cam assembly works, the parts, the fit test procedure
    to run before printing (gear first, then the fit test), why the parts need
    modifiers and which modifier belongs to which part, print settings, cam
    versions, optional gearbox parts, and design reference.
    Terms follow CONTEXT.md. Stale facts corrected: pin 6.00 mm, clearance
    default 0.05, gear_backlash -0.2. Vendor references removed.
2026-09-29 README: scope is Dominator replacement parts, not only the cam
    Title and intro now list the cam assembly and the gearbox parts, and the
    gearbox section is no longer labelled optional.
2026-09-29 CONTEXT: scope is Dominator replacement parts; add Gearbox parts term
    The title and intro cover the cam assembly and the gearbox parts. The
    reduction gear and drive shafts are gearbox parts, no longer an optional
    extra, and the reduction gear ring is dimensioned separately from the gear.
2026-09-29 Cam rim modifier: band depth equals the lobe height
    rim_band was a fixed 8 mm and reached too far toward the hub. It is now
    the taller lobe height (5 mm), so the band goes as deep below the trough
    circle as the lobes stand above it. One file still fits both versions.
    [config.scad, dominator_cam_rim_modifier.stl]
2026-09-29 Cam rim modifier: band 3 mm inside the trough circle
    5 mm was still too deep. rim_band is now a fixed 3 mm, the same for both
    cam versions.
    [config.scad, dominator_cam_rim_modifier.stl]
2026-09-29 Cam rim modifier: band 4 mm inside the trough circle
    3 mm was too shallow.
    [config.scad, dominator_cam_rim_modifier.stl]
2026-09-29 Gear plug modifier: tall enough for the reduction gear too
    Sized from the taller and wider of the gear with its plug (9.6 mm) and the
    reduction gear with plate and pinion (11.1 mm), so one modifier covers the
    plug on one and the pinion on the other.
    [cam_gear.scad, dominator_gear_plug_modifier.stl]
2026-09-29 Rename gear plug modifier to gear core modifier
    It now serves both the gear (plug) and the reduction gear (pinion), so
    the name says what it covers on either: the centre of the gear. The
    reduction gear gains a row in the modifier and print tables.
    [assembly.scad, cam_gear.scad, dominator_gear_core_modifier.stl]
2026-09-29 Tooth modifier serves the reduction gear ring; drop kit number
    gear_tooth_modifier now spans the smaller root, larger tip and thicker
    ring of the gear and the reduction gear, so it keeps fitting both if
    either ring changes. Listed for the reduction gear in README and SLICING.
    Removed a product kit number from the reduction_gear.scad header.
    [cam_gear.scad, reduction_gear.scad]
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2026-10-06 Add drive gear 1: compound 26 T over 19 T, solid body
    A gearbox drive gear the model did not cover. The 19 tooth gear is the taller
    of the two at 11 mm and the 26 tooth gear is 10 mm, as in the owner's
    measurements. Total 21 mm, which was measured separately from the two face
    widths, so all three numbers agree. The bore runs through both halves.
    Both halves share one module, taken from the 26 tooth gear. That reading is
    the trustworthy one because 26 is even, so a caliper straddles two opposite
    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
    [assembly.scad, config.scad, dominator_drive_gear_1.stl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]
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2026-10-07 Fix render_previews.ps1 quoting under pwsh 7.3+; add drive gear 3 view
    Same fix as render.ps1: the pre-escaped \" in the -D assignments reached
    OpenSCAD literally under pwsh 7.3+. Also lists the drive_gear_3 preview.
2026-10-07 Add drive gear 3: 26 T joining the drive shafts, printed in two halves
    A 26 tooth gear driven by drive gear 2, with an 18 mm boss on each face
    (5 mm short, 14 mm long) and an 8 lobe socket in each end for the drive
    shafts: short shaft 17 mm deep, long shaft 12 mm deep, a 1 mm solid wall
    between them at the gear face on the long side. No bore; the shafts carry
    it. Module from drive gear 1 (1.25, matching the 35 mm tip reading).
    The sockets use the drive shaft's own pinion profile grown by
    dg3_socket_clearance (0.3, a slide fit). The gear is cut across the axis
    at mid-height into two halves that print on their cut faces and are
    glued, aligned by four 1.75 mm filament dowels.
    [assembly.scad, config.scad, dominator_drive_gear_3.stl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]
2026-10-07 Drive gear 3: print in one piece by default
    Standing on the short boss it needs no supports: the wall is the only
    unsupported layer, a 13 mm bridge. One piece keeps the teeth whole and
    puts no glue joint in the long shaft's torque path. The two-half split
    stays available with dg3_split = true.
    [assembly.scad, config.scad, dominator_drive_gear_3.stl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]
2026-10-07 Drive gear 3: one piece needs supports under the gear
    The gear overhangs the 18 mm short boss from z = 5. Correct the README,
    config and module comments, and say how to keep supports out of the
    short socket.
    [config.scad, drive_gear.scad]
